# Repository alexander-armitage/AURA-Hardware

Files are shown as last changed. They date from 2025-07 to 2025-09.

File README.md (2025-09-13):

<div align="center">

# AURA
### Autonomous Universal Robotics Architecture

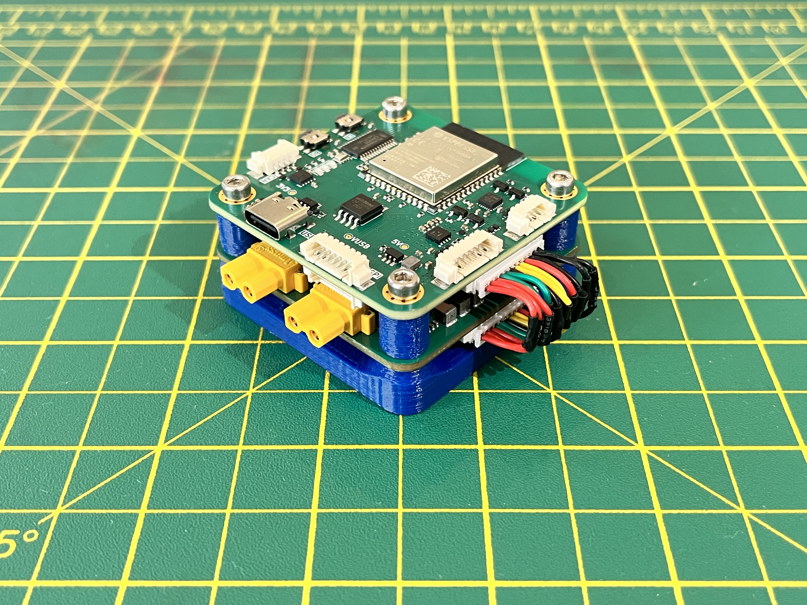
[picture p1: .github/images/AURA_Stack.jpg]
AURA PCBs Stacked


</div>

## Contents

1. [Overview](#overview)  
2. [Repository Structure](#repository-structure)
3. [License](#license)

## Overview

AURA (Autonomous Universal Robotics Architecture) is a modular set of PCBs designed for robotics applications. This repository includes schematics, layouts, and KiCad project files to facilitate prototyping and production.

The software framework to run on this hardware can be seen in another repository [here](https://github.com/alexander-armitage/AURA-Software).

### Features
#### MCU
- Dual Core 240MHz ESP32-S3
- Onboard IMU (ICM20948) 
- Onboard barometer (BMP280)
- Flash storage (128 MBit)
- SD card support
- 1x CAN connector
- 1x I2C connector
- 2x SPI connector
- 2x UART connectors
- 12x PWM output channels
- Power switching
- ESD protection

#### PDB
- 1x Battery pass-through
- 1x 5V 20A continuous output
- 2x high-current (10A) output channels
- 2S-6S LiPo battery input support
- Reverse polarity protection
- Power, Current, and Voltage sensing
- ESD protection

## Repository Structure

```
AURA-Hardware/
├── .github/              # Images for README
├── MCU_AURA/             # ESP32S3 based PCB project
│ ├── Gerber/             # Manufacturing files (JLCPCB)
│ ├── Libraries/          # Local project libraries
| ├── Pick_n_Place/       # Files to generate pick and place (JLCPCB)
│ └── MCU_AURA.kicad_pro  # Project file for KiCad
├── PDB_AURA/             # Power distribution board PCB project
│ ├── Gerber/             # Manufacturing files (JLCPCB)
│ ├── Libraries/          # Local project libraries
| ├── Pick_n_Place/       # Files to generate pick and place (JLCPCB)
│ └── PDB_AURA.kicad_pro  # Project file for KiCad
├── docs/                 # Schematics for the PCB projects
├── .gitignore            # Git ignore file
├── README.md             # Project overview
└── LICENSE               # License file
```

## License
See the [LICENSE](./LICENSE) file for more details.

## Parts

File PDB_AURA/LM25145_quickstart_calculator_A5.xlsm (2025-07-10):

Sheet: Design Regulator
LM(2)5145/46-Q1 DC-DC Controller Design Tool
About |  | xx (http://www.ti.com/pol) |  |  | = Input Box |  |  |  |  | TERMS OF USE
Step 1: Operating Specifications
 |  |  | Input Voltage ‒ Min, VIN(min) | 7.2 | V
 |  |  | Input Voltage ‒ Nom, VIN(nom) | 12.6 | V
 |  |  | Input Voltage ‒ Max, VIN(max) | 25.2 | V
 |  |  | Output Voltage, VOUT | 5 | V
 |  |  | Maximum Output Current, IOUT | 20 | A
 |  |  | Free-running Switching Frequency, FSW | 256 | kHz
 |  |  | SYNC Frequency (if used), FSW-SYNC | 256 | kHz
 |  |  | Frequency Set Resistor, RRT | 39.2 | kΩ
Step 2: Filter Inductor
 |  |  | Recommended Filter Inductance | 1.8 | µH
 |  |  | Inductance, LF | 1.8 | µH
 |  |  | Inductor DCR | 5 | mΩ
 |  |  | Pk-to-Pk Ripple Current at VIN(nom), DIL | 6.8 | Apk-pk
 |  |  | Inductor Ripple Current as a % of Max IOUT | 34.16418651 | %
 |  |  | Estimate Core Loss at VIN(nom) | 0.2 | W
Step 3: RDS(on) or Shunt-Based Current Limit
 |  |  | Shunt, RS | 6 | mΩ |  |  |  |  |  | \
 |  |  | Required Current Limit Setpoint | 20 | A
 |  |  | Current Limit Set Resistor, RILIM | 499 | Ω
 |  |  | Min Inductor Sat Current, IL(SAT) | 27.6 | A
 |  |  | Power Loss in RS at Full Load, Max VIN | 1.54 | W
Step 4: Output Capacitance
 |  |  | Output Voltage Ripple Specification | 200 | mVpk-pk
 |  |  | Minimum Ideal Output Capacitance | 16.68173169 | µF
 |  |  | Total Output Capacitance (Derated), COUT | 100 | µF
 |  |  | Maximum Permitted ESR | 28.86027509 | mΩ
 |  |  | Output Capacitor ESR | 1 | mΩ
 |  |  | Resulting Output Voltage Ripple | 34.05595917 | mVpk-pk
 |  |  | Output Capacitor Ripple Current | 2.0 | A (rms)
Step 5: Input Capacitance
 |  |  | Input Voltage Ripple Specification | 500 | mVpk-pk
 |  |  | Minimum Ideal Input Capacitance | 37.91454082 | µF
 |  |  | Total Input Capacitance (Derated), CIN | 150 | µF
 |  |  | Maximum Permitted ESR | 15.9553945 | mΩ
 |  |  | Input Capacitor ESR | 2 | mΩ
 |  |  | Resulting Input Voltage Ripple | 173.21464 | mVpk-pk
 |  |  | Input Capacitor Ripple Current | 9.9 | A (rms)
Step 6: Soft-start, UVLO
 |  |  | Soft-Start Time, tSS | 4 | ms
 |  |  | Soft-Start Capacitance, CSS | 47 | nF
 |  |  | Input Voltage UVLO Turn-On | 34 | V
 |  |  | Input Voltage UVLO Turn-Off | 30 | V
 |  |  | UVLO Upper Resistor, RUV1 | 402 | kΩ
 |  |  | UVLO Lower Resistor, RUV2 | 14.7 | kΩ
If the SYNC feature is not required, connect SYNCIN to GND
or VCC for DCM or CCM operation, respectively
Step 7: Compensation Design
 |  |  | LC Complex Pole Frequency | 12.0 | kHz
 |  |  | ESR Zero Frequency | 1591.549433 | kHz
 |  |  | Desired Crossover Frequency | 40 | kHz
 |  |  | Appropriate Midband Gain | 0.22 | V/V
 |  |  | Upper Feedback Resistor, RFB1 | 10.5 | kΩ
 |  |  | Lower Feedback Resistor, RFB2 | 2 | kΩ
 |  |  | Actual Output Voltage, VOUT | 5.000 | V
Pole & Zero Placement |  |  | FZ1 | 8.4 | kHz
Baseline P/Z Frequencies: |  |  | FZ2 | 10.8 | kHz
 |  |  | FP1 | 1591.549433 | kHz
 |  |  | FP2 | 128 | kHz
Compensation Components
 | Calculated / | Std Values | Selected |  | Actual P/Z Frequencies
RC1 | 2.3 | 2.32 | 1 | kΩ | 8.8 | kHz (FZ1)
CC1 | 8120.150167 | 8200 | 18000 | pF | 8.4 | kHz (FZ2)
CC2 | 568.1178809 | 560 | 1000 | pF | 4019.064224 | kHz (FP1)
RC2 | 71.47847597 | 71.5 | 22 | Ω | 167.9968846 | kHz (FP2)
CC3 | 1399.022554 | 1500 | 1800 | pF |  |  | ** Specify Inductor Core Loss ** | 0.4 | W
Efficiency / Power Loss Analyzer
Step 8: Efficiency
 |  |  | High-Side MOSFET (Q1) Specifications | CSD18563Q5D
 |  |  | On-State Resistance, RDS(on) | 6 | mΩ
 |  |  | Total Gate Charge, QG | 11.5 | nC
 |  |  | Gate-Drain Charge, QGD | 2.9 | nC
 |  |  | Gate-Source Charge, QGS | 3.3 | nC
 |  |  | Output Capacitance, COSS | 280 | pF
 |  |  | Gate Resistance, RG | 1.5 | Ω
 |  |  | Transconductance, gFS | 100 | S
 |  |  | Gate-Source Plateau Voltage, VGS(MP) | 3.2 | V
 |  |  | Body Diode Forward Voltage, VBD1 | 0.8 | V
 |  |  | Thermal Resistance, θJA | 50 | °C/W
 |  |  | Low-Side MOSFET (Q2) Specifications | CSD18563Q5D
 |  |  | On-State Resistance, RDS(on) | 6 | mΩ
 |  |  | Total Gate Charge, QG | 11.5 | nC
 |  |  | Output Charge, QOSS | 20 | nC
 |  |  | Output Capacitance, COSS | 280 | pF
 |  |  | Body Diode Forward Voltage, VBD2 | 0.9 | V
 |  |  | Body Diode Recovery Charge, QRR | 63 | nC
 |  |  | Thermal Resistance, θJA | 50 | °C/W
 |  |  | Antiparallel Schottky Diode (if applicable)
 |  |  | Schottky Diode Forward Voltage, VSD | 0 | V
 |  |  | Schottky Diode Recovery Charge, QRR2 | 0 | nC
Step 9: IC Power Loss
 |  |  | IC Power Dissipation | 0.07 | W
 |  |  | IC Junction Temperature Rise (est) | 3.5 | °C

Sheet: Schematic & BOM
 | ** Tie SYNCIN to VCC and GND for CCM and DCM operation, respectively **
VIN = 12.6 V, VOUT = 5 V, IOUT = 20 A, Fsw = 256 kHz, Current Limit = 20 A
Wide VIN, High Efficiency Synchronous Buck Regulator BOM
Count | Ref Des | Value | Description | Size | Part Number | MFR | Footprint (mm) | Area (mm2)
1 | CBOOT | 0.1µF | Capacitor, Ceramic,0.1µF, 25V, X7R, 20% |  | Std | Std | 1.6 x 0.8 | 1.3 |  |  |  | 2
1 | CC1 | 18000pF | Capacitor, Ceramic,18000pF, 16V, X7R, 10% |  | Std | Std | 1.0 x 0.5 | 0.5 |  |  |  | 1
1 | CC2 | 1000pF | Capacitor, Ceramic,1000pF, 50V, NP0, 5% |  | Std | Std | 1.0 x 0.5 | 0.5 |  |  |  | 1
1 | CC3 | 1800pF | Capacitor, Ceramic,1800pF, 50V, NP0, 5% |  | Std | Std | 1.0 x 0.5 | 0.5 |  |  |  | 1
1 | CS | 10pF | Capacitor, Ceramic, 10pF, 100V, X7R, 20% |  | Std | Std | 1.6 x 0.8 | 1.3 |  |  |  | 2
15 | CIN | 4.7µF | Capacitor, Ceramic, 4.7µF, 50V, X7R, 10% |  | Std | Std | 3.2 x 2.5 | 120.0 |  |  |  | 5
3 | COUT | 47µF | Capacitor, Ceramic, 47µF, 10V, X7R, 10% |  | Std | Std | 3.2 x 2.5 | 24.0 |  |  |  | 5
1 | CSS | 47nF | Capacitor, Ceramic,47nF, 16V, X7R, 10% |  | Std | Std | 1.6 x 0.8 | 1.3 |  |  |  | 2
1 | CVCC | 2.2µF | Capacitor, Ceramic,2.2µF, 25V, X7R, 20% |  | Std | Std | 2.0 x 1.25 | 2.5 |  |  |  | 3
1 | CVIN | 0.1µF | Capacitor, Ceramic,0.1µF, 50V, X7R, 20% |  | Std | Std | 1.6 x 0.8 | 1.3 |  |  |  | 2
1 | LF | 1.8µH | Inductor, 1.8µH, 5mΩ, >28A |  | Various | Various | 10.0 x 10.0 | 100.0 |  |  |  | 7
1 | Q1 | See description | MOSFET, N-CH, 80V/100V,6mΩ |  | CSD18563Q5D | TI | 5.0 x 6.0 | 30.0 |  |  |  | 1 | 1
1 | Q2 | See description | MOSFET, N-CH, 80V/100V,6mΩ |  | CSD18563Q5D | TI | 5.0 x 6.0 | 30.0 |  |  |  | 1 | 1
1 | RC1 | 1k | Resistor, Chip,1kΩ, 1/16W, 1% |  | Std | Std | 1.0 x 0.5 | 0.5 |  |  |  | 1
1 | RC2 | 22 | Resistor, Chip,22Ω, 1/16W, 1% |  | Std | Std | 1.0 x 0.5 | 0.5 |  |  |  | 1
1 | RILIM | 499 | Resistor, Chip,499Ω, 1/16W, 1% |  | Std | Std | 1.0 x 0.5 | 2.5 |  |  |  | 3
1 | RRT | 39.2k | Resistor, Chip,39.2kΩ, 1/16W, 1% |  | Std | Std | 1.0 x 0.5 | 0.5 |  |  |  | 1
1 | RFB1 | 10.5k | Resistor, Chip,10.5kΩ, 1/16W, 1% |  | Std | Std | 1.0 x 0.5 | 0.5 |  |  |  | 1
1 | RFB2 | 2k | Resistor, Chip,2kΩ, 1/16W, 1% |  | Std | Std | 1.0 x 0.5 | 0.5 |  |  |  | 1
1 | RPGOOD | 20k | Resistor, Chip,20kΩ, 1/16W, 1% |  | Std | Std | 1.0 x 0.5 | 0.5 |  |  |  | 1
1 | RS | 6mΩ | Resistor,6mΩ, 1/4W, 1% | 1206 | Std | Std | 3.2 x 1.6 | 0.0
1 | RUV1 | 402k | Resistor, Chip,402kΩ, 1/16W, 1% |  | Std | Std | 1.6 x 0.8 | 1.3 |  |  |  | 2
1 | RUV2 | 14.7k | Resistor, Chip,14.7kΩ, 1/16W, 1% |  | Std | Std | 1.0 x 0.5 | 0.5 |  |  |  | 1
1 | RVIN | 2.2 | Resistor, Chip,2.2Ω, 1/16W, 1% |  | Std | Std | 1.0 x 0.5 | 0.5 |  |  |  | 1
1 | U1 | LM25145 | IC, LM25145, PWM Controller, 6V-42V Input | VQFN-20 | LM25145RGYR | TI | 3.5 x 4.5 x 1.0 | 15.75
 |  |  |  |  | Total Solution Size (buffered by 25%) |  |  | 420.9 | mm2 = | 0.6525 | in2
NOTES:
** Inductor saturation current should be higher than the current limit setpoint at all operating temperatures **
** Effective output capacitance should be appropriately derated for applied voltage and temperature, particularly with ceramics **
 |  |  |  |  |  |  |  |  |  |  |  | 2

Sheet: EVMs
LM(2)5145/6/-Q1 Quickstart Calculator
 | LM5146-Q1-EVM12V
 | LM5145EVM-HD-20A PCB Layout
 |  | Top
 |  | Layer | x
 |  | Layer 2
 |  | Layer 3
 |  | Bottom

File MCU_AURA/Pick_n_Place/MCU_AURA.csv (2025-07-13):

Value | Reference | Footprint | JLCPCB Part#
100n | C1,C102,C103,C104,C201,C203,C204,C205,C206,C300,C301,C302,C303,C304,C305,C402 | Capacitor_SMD:C_0402_1005Metric | C1525
10u | C100,C105,C107,C202,C400 | Capacitor_SMD:C_0402_1005Metric | C15525
1u | C101,C108,C109,C401 | Capacitor_SMD:C_0402_1005Metric | C52923
4u7 | C106 | Capacitor_SMD:C_0805_2012Metric | C23733
22u | C200 | Capacitor_SMD:C_0402_1005Metric | C415703
TPD1E05U06DPYR | D100,D101,D102,D400,D401,D402,D403,D404,D405,D406,D407,D408,D409,D410 | TPD1E05U06DPYR:DIO_TPD1E05U06DPYR | C2937017
LED | D103,D104,D300 | LED_SMD:LED_0603_1608Metric | C2286
PCA9685PW,118 | IC1 | PCA9685PW_118:SOP65P640X110-28N | C2678753
W25Q128JVSIQ | IC2 | SOIC127P790X216-8N | C97521
USB_C_Receptacle_USB2.0_16P | J100 | USB-C:USB_C_Receptacle_GCT_USB4105-xx-A_16P_TopMnt_Horizontal | C19189138
532617004 | J400,J402 | 532610471:53261-0471 | C696092
532617007 | J405,J407 | 532610771:532610771 | C505276
2u2 | L101 | Inductor_SMD:L_1008_2520Metric | C92925
BSS138 | Q300,Q301,Q302 | Package_TO_SOT_SMD:SOT-23 | C7420339
10k | R1,R103,R200,R205,R206,R300,R301,R302,R303,R304,R306,R400,R401 | Resistor_SMD:R_0402_1005Metric | C25744
5k1 | R100,R101 | Resistor_SMD:R_0402_1005Metric | C25905
270R | R102 | Resistor_SMD:R_0402_1005Metric | C163474
1k | R104 | Resistor_SMD:R_0402_1005Metric | C11702
6k8 | R106 | Resistor_SMD:R_0402_1005Metric | C25917
1k5 | R107 | Resistor_SMD:R_0402_1005Metric | C25867
470R | R108,R305 | Resistor_SMD:R_0402_1005Metric | C25117
22R | R201,R202 | Resistor_SMD:R_0402_1005Metric | C25092
EVQPUC02K | S200,S201 | EVQ-PUC02k:EVQPUC02K | EVQPUC02K
TPS2115ADRBR | U100 | TPS2115ADRBR:SON65P300X300X100-9N-D | C140321
TLV62566DBVR | U101 | TLV62566DBVR:SOT95P280X145-5N | C2070898
AP2127N-1.8 | U102 | Package_TO_SOT_SMD:SOT-23 | C780749
ESP32-S3-WROOM-1 | U200 | RF_Module:ESP32-S3-WROOM-1 | C2913198
USBLC6-2SC6 | U201 | Package_TO_SOT_SMD:SOT-23-6 | C7519
TCAN1042VDRBRQ1 | U202 | TCAN1042VDRBRQ1:DRB0008F | C2652857
ICM-20948 | U300 | Sensor_Motion:InvenSense_QFN-24_3x3mm_P0.4mm | C726001
BMP280 | U301 | Package_LGA:Bosch_LGA-8_2x2.5mm_P0.65mm_ClockwisePinNumbering | C83291

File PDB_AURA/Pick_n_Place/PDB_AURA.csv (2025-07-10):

Value | Reference | Footprint | JLCPCB Part#
47n | C101,C211 | Capacitor_SMD:C_0402_1005Metric | C272875
47u | C102,C200,C201,C204,C205,C216 | Capacitor_SMD:C_1210_3225Metric | C7432791
22n | C104 | Capacitor_SMD:C_0402_1005Metric | C1532
100n | C202,C207,C208,C215,C217,C300 | Capacitor_SMD:C_0402_1005Metric | C307331
1u | C203,C218 | Capacitor_SMD:C_0402_1005Metric | C52923
2u2 | C209 | Capacitor_SMD:C_0402_1005Metric | C107369
10p | C210 | Capacitor_SMD:C_0402_1005Metric | C32949
1n | C212 | Capacitor_SMD:C_0402_1005Metric | C1523
18n | C213 | Capacitor_SMD:C_0402_1005Metric | C5448818
1n8 | C214 | Capacitor_SMD:C_0402_1005Metric | C527007
LED | D100,D200 | LED_SMD:LED_0603_1608Metric | C2286
SBR3M30P17 | D300,D301 | SBR3M30P17:SBR3M30P17 | C460953
1u8 | L200 | 125CDMCCDS-1R8MC:Untitled | C2453926
CSD18540Q5B | Q100,Q200,Q201 | CSD18540Q5B:CSD18540Q5B | C86513
HSK10N06 | Q300,Q301 | HSK10N06:HSK10N06 | C5128195
0m5 | R100 | Resistor_SMD:R_2512_6332Metric | C500733
2k2 | R101 | Resistor_SMD:R_0402_1005Metric | C25879
0R | R200 | Resistor_SMD:R_0402_1005Metric | C17168
39k | R201,R208 | Resistor_SMD:R_0402_1005Metric | C25783
10k | R202,R203,R209,R300,R302,R304,R306 | Resistor_SMD:R_0402_1005Metric | C25744
22R | R204 | Resistor_SMD:R_0402_1005Metric | C25092
2k | R205 | Resistor_SMD:R_0402_1005Metric | C4109
1k | R207,R211 | Resistor_SMD:R_0402_1005Metric | C11702
10.5k | R206 | Resistor_SMD:R_0402_1005Metric | C25850
470R | R210 | Resistor_SMD:R_0402_1005Metric | C25117
220R | R301,R305 | Resistor_SMD:R_0402_1005Metric | C25091
100R | R303,R307 | Resistor_SMD:R_0402_1005Metric | C25076
LM74700 | U100 | Package_TO_SOT_SMD:SOT-23-6 | C2941042
LM25145RGYR | U200 | LM24145RGYR:RGY0020B | C2876740
LTV-217-B-G | U300,U301 | LTV-217-B-G:SOIC127P700X210-4N | C115450
INA219AIDCNR | U302 | INA219AIDCNR:SOT65P280X145-8N | C87469

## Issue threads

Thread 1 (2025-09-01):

USB ESD Protection IC (USBLC6-2SC6) Backfeeds VUSB via D+ / D−

alexander-armitage, 2025-09-01:
When powering the MCU board through the PDB, the 5 V rail oscillates on and off, causing the onboard LED to blink. The PDB itself provides a stable 5 V output, and the MCU operates normally when powered directly via USB.

The USBLC6-2SC6 protection device appears to be backfeeding VUSB through the D+ and D− lines.

Closed 2025-09-07.

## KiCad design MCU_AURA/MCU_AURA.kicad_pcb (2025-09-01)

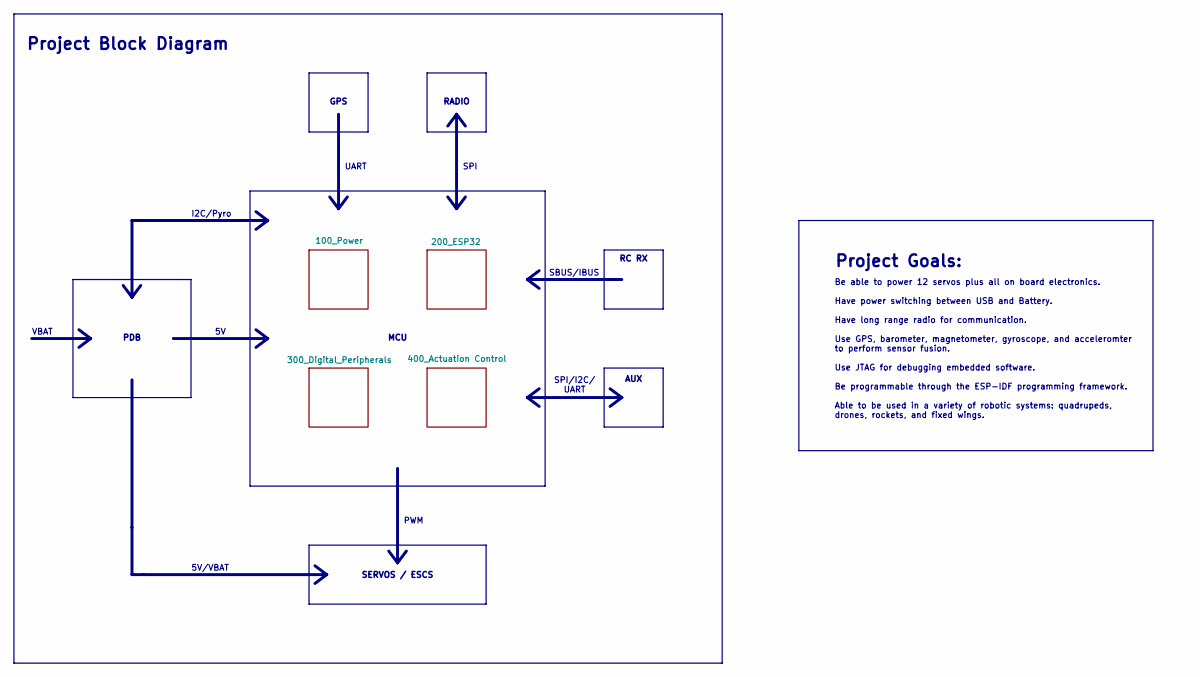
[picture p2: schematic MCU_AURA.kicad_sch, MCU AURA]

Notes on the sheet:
GPS
SPI
SPI/I2C/ UART
UART
Be able to power 12 servos plus all on board electronics. Have power switching between USB and Battery. Have long range radio for communication. Use GPS, barometer, magnetometer, gyroscope, and acceleromter to perform sensor fusion. Use JTAG for debugging embedded software. Be programmable through 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
SBUS/IBUS
RADIO
PDB
I2C/Pyro
Project Block Diagram
MCU
Project Goals:
5V/VBAT
PWM
VBAT
AUX
RC RX
SERVOS / ESCS

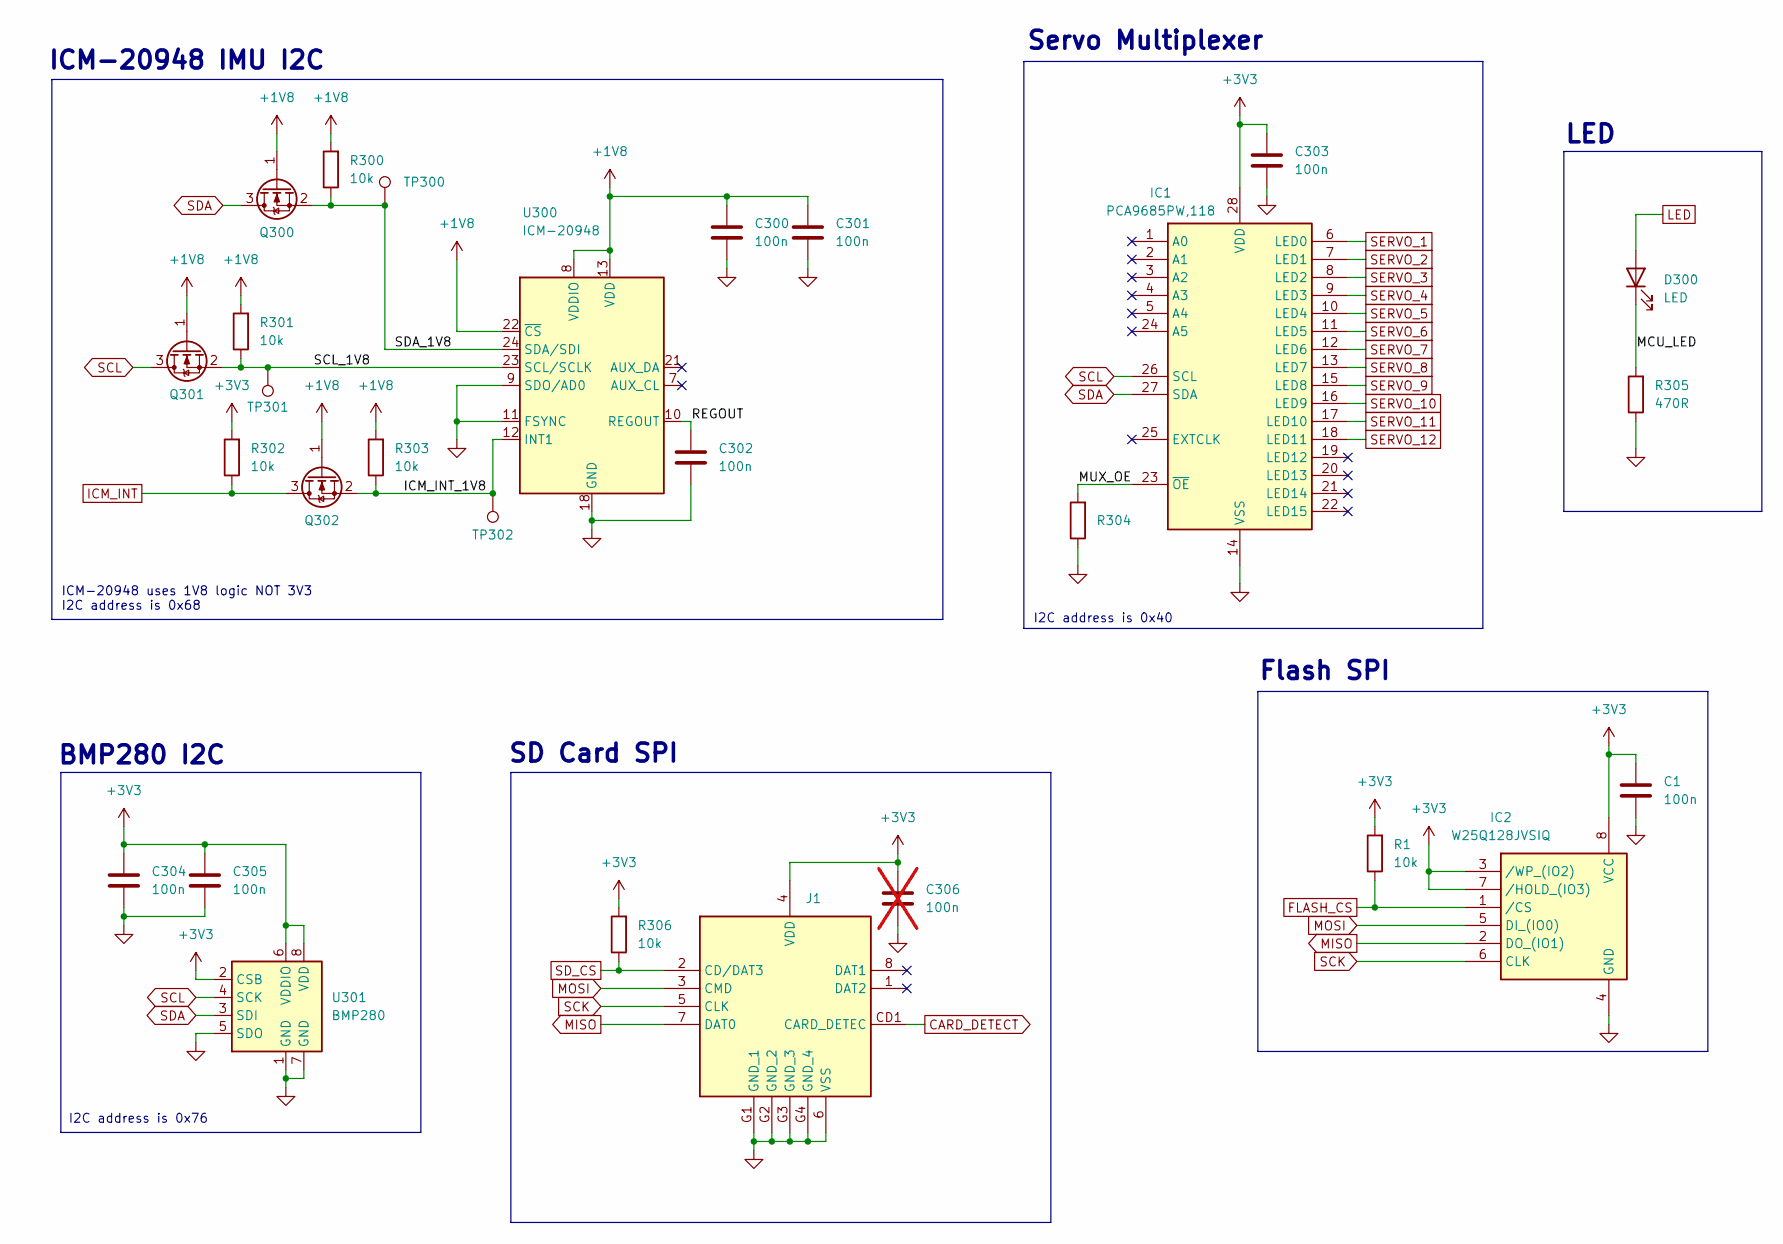
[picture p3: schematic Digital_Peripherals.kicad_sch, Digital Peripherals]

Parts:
C1, C300, C301, C302, C303, C304, C305: 100n; C_0402_1005Metric
C306: 100n; C_0402_1005Metric; not fitted
D300: LED; LED_0603_1608Metric
IC1: PCA9685PW,118; SOP65P640X110-28N; Manufacturer_Part_Number PCA9685PW,118; Mouser Part Number 771-PCA9685PW,118
IC2: W25Q128JVSIQ; SOIC127P790X216-8N; Manufacturer_Part_Number W25Q128JVSIQ; Mouser Part Number 454-W25Q128JVSIQ
J1: TF-CARD_H1.8; TFCARDH18; Manufacturer_Part_Number TF-CARD H1.8
Q300, Q301, Q302: BSS138; SOT-23
R1, R300, R301, R302, R303, R304, R306: 10k; R_0402_1005Metric
R305: 470R; R_0402_1005Metric
TP300, TP301, TP302: TestPoint; TestPoint_Pad_D1.0mm
U300: ICM-20948; InvenSense_QFN-24_3x3mm_P0.4mm
U301: BMP280; Bosch_LGA-8_2x2.5mm_P0.65mm_ClockwisePinNumbering

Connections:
+1V8: C300.1, C301.1, Q300.1 (G), Q301.1 (G), Q302.1 (G), R300.2, R301.2, R303.2, U300.8 (VDDIO), U300.13 (VDD), U300.22 (~CS); also elsewhere on the board
+3V3: C1.1, C303.1, C304.1, C305.1, C306.1, IC1.28 (VDD), IC2.3 (/WP_(IO2)), IC2.7 (/HOLD_(IO3)), IC2.8 (VCC), J1.4 (VDD), R1.2, R302.2, R306.2, U301.2 (CSB), U301.6 (VDDIO), U301.8 (VDD); also elsewhere on the board
/300_Digital_Peripherals/ICM_INT_1V8: Q302.2 (S), R303.1, TP302.1, U300.12 (INT1)
/300_Digital_Peripherals/MCU_LED: D300.1 (K), R305.2
/300_Digital_Peripherals/MUX_OE: IC1.23 (~OE), R304.2
/300_Digital_Peripherals/REGOUT: C302.1, U300.10 (REGOUT)
/300_Digital_Peripherals/SCL_1V8: Q301.2 (S), R301.1, TP301.1, U300.23 (SCL/SCLK)
/300_Digital_Peripherals/SDA_1V8: Q300.2 (S), R300.1, TP300.1, U300.24 (SDA/SDI)
CARD_DETECT: J1.CD1 (CARD_DETEC); also elsewhere on the board
FLASH_CS: IC2.1 (/CS), R1.1; also elsewhere on the board
GND: C1.2, C300.2, C301.2, C302.2, C303.2, C304.2, C305.2, C306.2, IC1.14 (VSS), IC2.4 (GND), J1.6 (VSS), J1.G1 (GND_1), J1.G2 (GND_2), J1.G3 (GND_3), J1.G4 (GND_4), R304.1, R305.1, U300.9 (SDO/AD0), U300.11 (FSYNC), U300.18 (GND), U300.20 (GND), U301.1 (GND), U301.5 (SDO), U301.7 (GND); also elsewhere on the board
ICM_INT: Q302.3 (D), R302.1; also elsewhere on the board
LED: D300.2 (A); also elsewhere on the board
MISO: IC2.2 (DO_(IO1)), J1.7 (DAT0); also elsewhere on the board
MOSI: IC2.5 (DI_(IO0)), J1.3 (CMD); also elsewhere on the board
SCK: IC2.6 (CLK), J1.5 (CLK); also elsewhere on the board
SCL: IC1.26 (SCL), Q301.3 (D), U301.4 (SCK); also elsewhere on the board
SDA: IC1.27 (SDA), Q300.3 (D), U301.3 (SDI); also elsewhere on the board
SD_CS: J1.2 (CD/DAT3), R306.1; also elsewhere on the board
SERVO_1: IC1.6 (LED0); also elsewhere on the board
SERVO_2: IC1.7 (LED1); also elsewhere on the board
SERVO_3: IC1.8 (LED2); also elsewhere on the board
SERVO_4: IC1.9 (LED3); also elsewhere on the board
SERVO_5: IC1.10 (LED4); also elsewhere on the board
SERVO_6: IC1.11 (LED5); also elsewhere on the board
SERVO_7: IC1.12 (LED6); also elsewhere on the board
SERVO_8: IC1.13 (LED7); also elsewhere on the board
SERVO_9: IC1.15 (LED8); also elsewhere on the board
SERVO_10: IC1.16 (LED9); also elsewhere on the board
SERVO_11: IC1.17 (LED10); also elsewhere on the board
SERVO_12: IC1.18 (LED11); also elsewhere on the board

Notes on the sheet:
Flash SPI
I2C address is 0x40
I2C address is 0x76
BMP280 I2C
SD Card SPI
ICM-20948 IMU I2C
Servo Multiplexer
ICM-20948 uses 1V8 logic NOT 3V3 I2C address is 0x68
LED

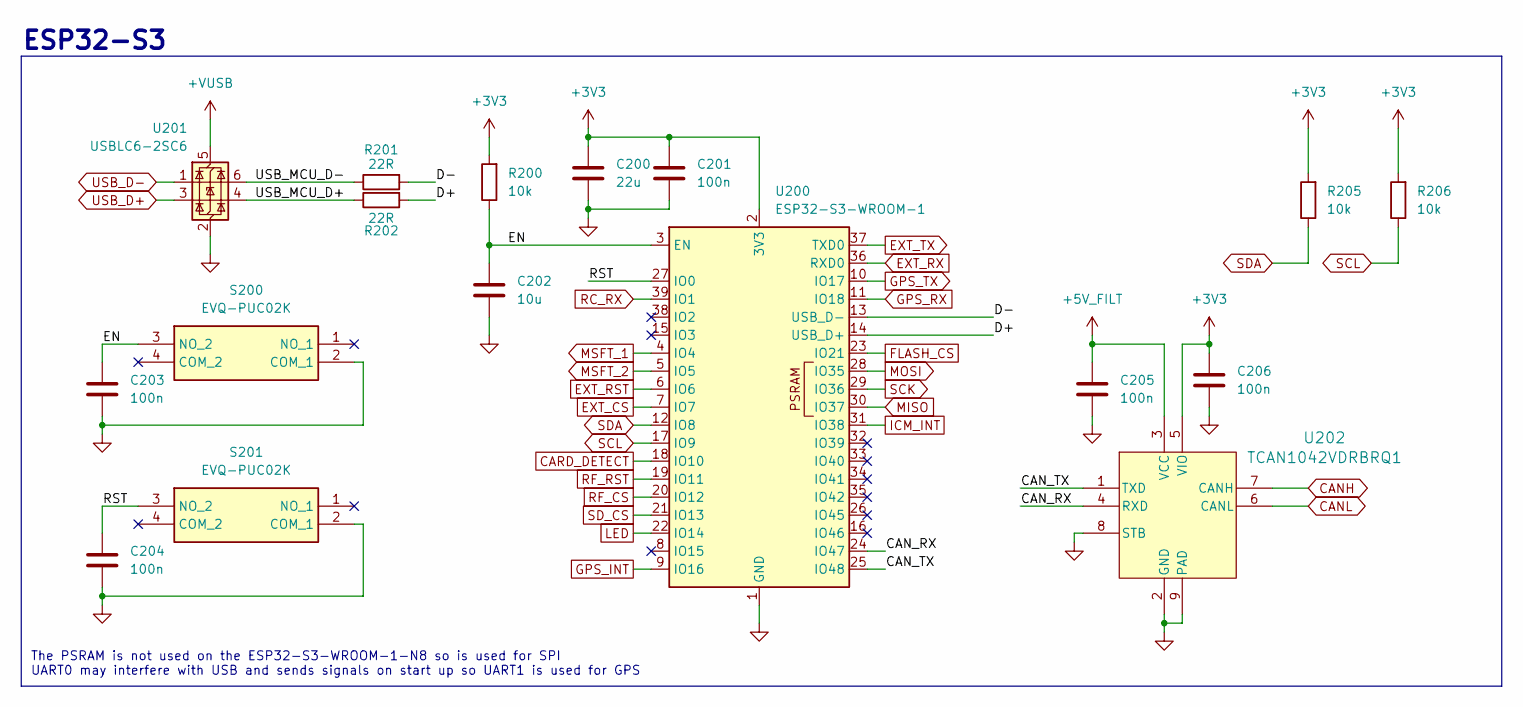
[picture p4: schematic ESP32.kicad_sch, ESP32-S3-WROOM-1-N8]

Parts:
C200: 22u; C_0402_1005Metric
C201, C203, C204, C205, C206: 100n; C_0402_1005Metric
C202: 10u; C_0402_1005Metric
R200, R205, R206: 10k; R_0402_1005Metric
R201, R202: 22R; R_0402_1005Metric
S200, S201: EVQ-PUC02K; EVQPUC02K; Manufacturer_Part_Number EVQ-PUC02K; Mouser Part Number 667-EVQ-PUC02K
U200: ESP32-S3-WROOM-1
U201: USBLC6-2SC6; SOT-23-6
U202: TCAN1042VDRBRQ1; DRB0008F

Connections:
+3V3: C200.1, C201.1, C206.1, R200.2, R205.2, R206.2, U200.2 (3V3), U202.5 (VIO); also elsewhere on the board
+5V_FILT: C205.1, U202.3 (VCC); also elsewhere on the board
+VUSB: U201.5 (VBUS); also elsewhere on the board
/200_ESP32/CAN_RX: U200.24 (IO47), U202.4 (RXD)
/200_ESP32/CAN_TX: U200.25 (IO48), U202.1 (TXD)
/200_ESP32/D+: R202.2, U200.14 (USB_D+)
/200_ESP32/D-: R201.2, U200.13 (USB_D-)
/200_ESP32/EN: C202.1, C203.1, R200.1, S200.3 (NO_2), U200.3 (EN)
/200_ESP32/RST: C204.1, S201.3 (NO_2), U200.27 (IO0)
/200_ESP32/USB_MCU_D+: R202.1, U201.4 (I/O2)
/200_ESP32/USB_MCU_D-: R201.1, U201.6 (I/O1)
CANH: U202.7 (CANH); also elsewhere on the board
CANL: U202.6 (CANL); also elsewhere on the board
CARD_DETECT: U200.18 (IO10); also elsewhere on the board
EXT_CS: U200.7 (IO7); also elsewhere on the board
EXT_RST: U200.6 (IO6); also elsewhere on the board
EXT_RX: U200.36 (RXD0); also elsewhere on the board
EXT_TX: U200.37 (TXD0); also elsewhere on the board
FLASH_CS: U200.23 (IO21); also elsewhere on the board
GND: C200.2, C201.2, C202.2, C203.2, C204.2, C205.2, C206.2, S200.2 (COM_1), S201.2 (COM_1), U200.1 (GND), U200.40 (GND), U200.41 (GND), U201.2 (GND), U202.2 (GND), U202.8 (STB), U202.9 (PAD); also elsewhere on the board
GPS_INT: U200.9 (IO16); also elsewhere on the board
GPS_RX: U200.11 (IO18); also elsewhere on the board
GPS_TX: U200.10 (IO17); also elsewhere on the board
ICM_INT: U200.31 (IO38); also elsewhere on the board
LED: U200.22 (IO14); also elsewhere on the board
MISO: U200.30 (IO37); also elsewhere on the board
MOSI: U200.28 (IO35); also elsewhere on the board
MSFT_1: U200.4 (IO4); also elsewhere on the board
MSFT_2: U200.5 (IO5); also elsewhere on the board
RC_RX: U200.39 (IO1); also elsewhere on the board
RF_CS: U200.20 (IO12); also elsewhere on the board
RF_RST: U200.19 (IO11); also elsewhere on the board
SCK: U200.29 (IO36); also elsewhere on the board
SCL: R206.1, U200.17 (IO9); also elsewhere on the board
SDA: R205.1, U200.12 (IO8); also elsewhere on the board
SD_CS: U200.21 (IO13); also elsewhere on the board
USB_D+: U201.3 (I/O2); also elsewhere on the board
USB_D-: U201.1 (I/O1); also elsewhere on the board

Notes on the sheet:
The PSRAM is not used on the ESP32-S3-WROOM-1-N8 so is used for SPI UART0 may interfere with USB and sends signals on start up so UART1 is used for GPS
ESP32-S3

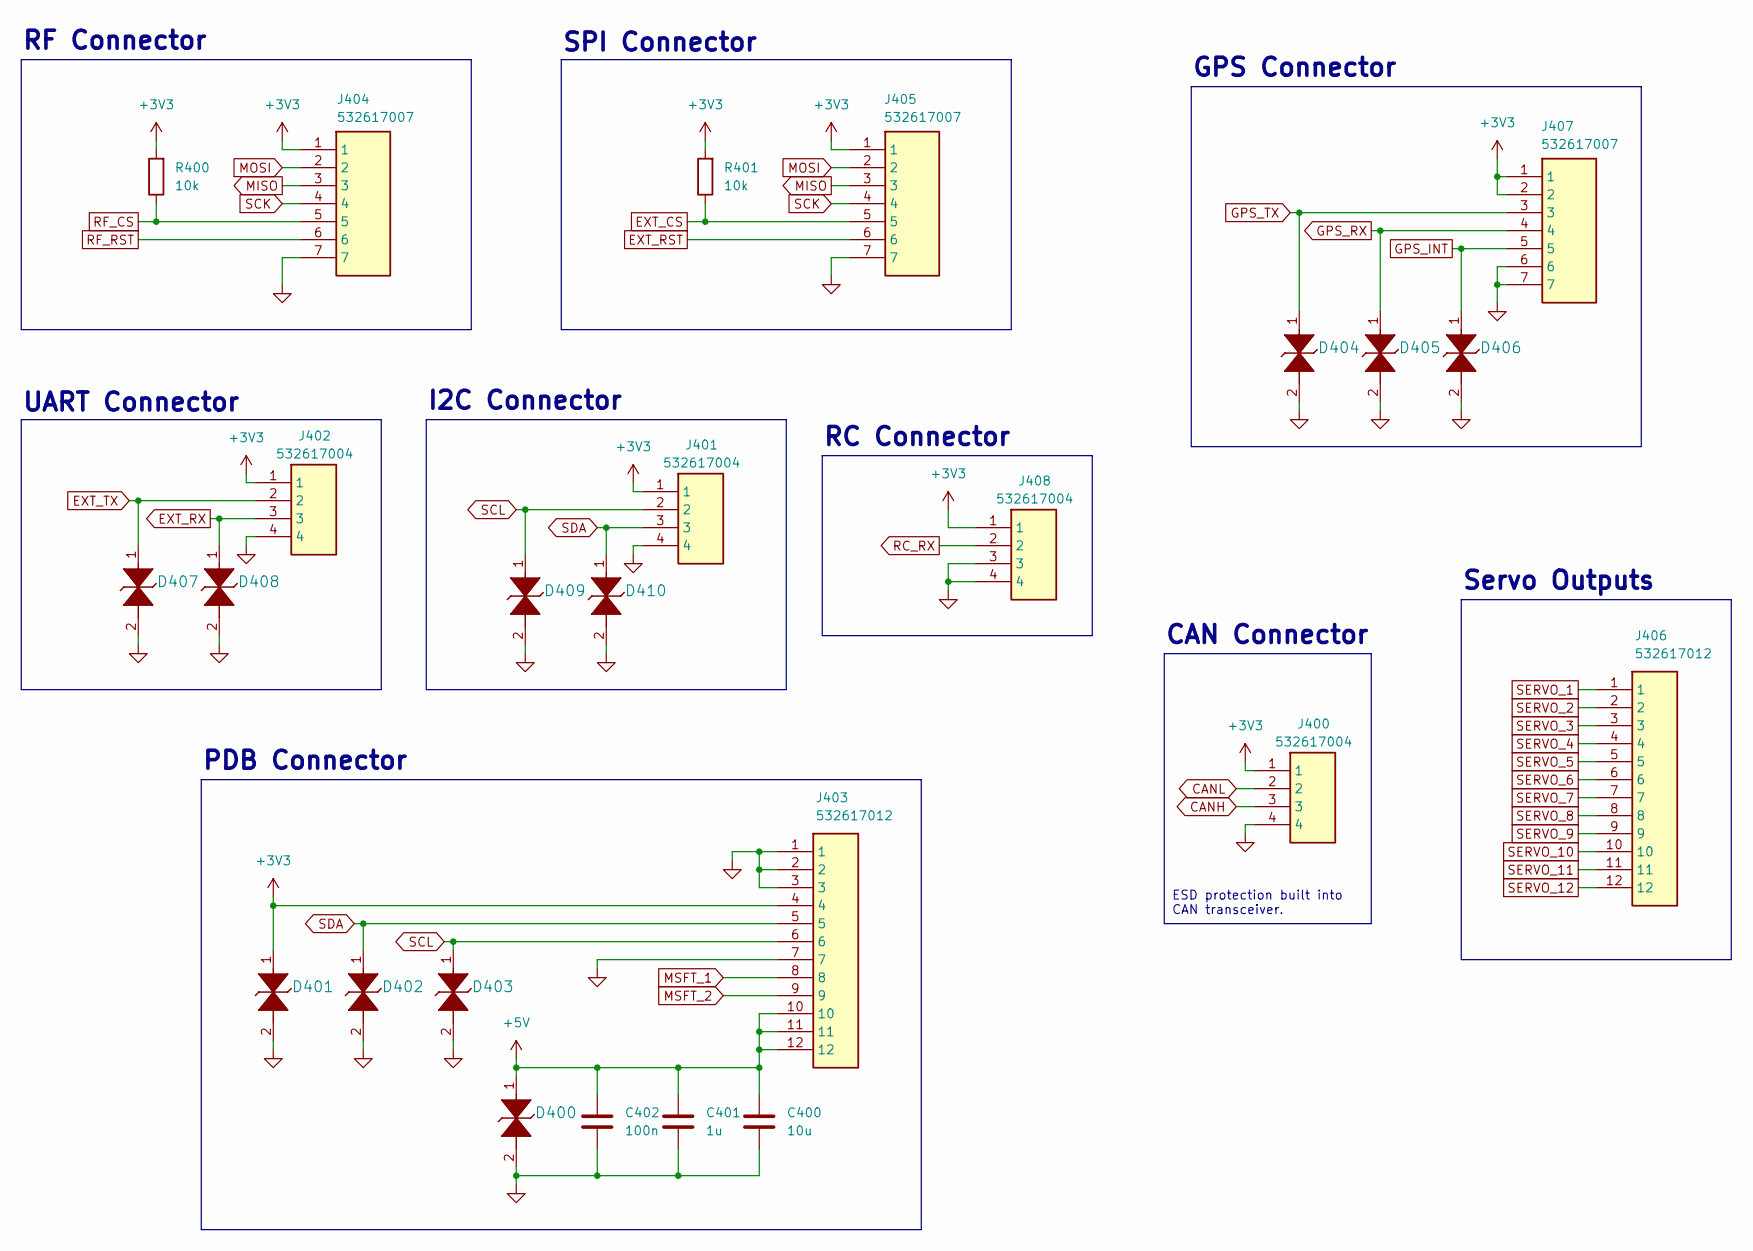
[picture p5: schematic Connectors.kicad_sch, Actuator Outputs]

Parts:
C400: 10u; C_0402_1005Metric
C401: 1u; C_0402_1005Metric
C402: 100n; C_0402_1005Metric
D400, D401, D402, D403, D404, D405, D406, D407, D408, D409, D410: TPD1E05U06DPYR; DIO_TPD1E05U06DPYR
J400, J401, J402, J408: 532617004; 53261-0471; Manufacturer_Part_Number 532617004
J403, J406: 532617012; 53261-1271; Manufacturer_Part_Number 532617012
J404, J405, J407: 532617007; 532610771; Manufacturer_Part_Number 532617007
R400, R401: 10k; R_0402_1005Metric

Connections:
+3V3: D401.1, J400.1, J401.1, J402.1, J403.4, J404.1, J405.1, J407.1, J407.2, J408.1, R400.2, R401.2; also elsewhere on the board
+5V: C400.1, C401.1, C402.1, D400.1, J403.10, J403.11, J403.12; also elsewhere on the board
CANH: J400.3; also elsewhere on the board
CANL: J400.2; also elsewhere on the board
EXT_CS: J405.5, R401.1; also elsewhere on the board
EXT_RST: J405.6; also elsewhere on the board
EXT_RX: D408.1, J402.3; also elsewhere on the board
EXT_TX: D407.1, J402.2; also elsewhere on the board
GND: C400.2, C401.2, C402.2, D400.2, D401.2, D402.2, D403.2, D404.2, D405.2, D406.2, D407.2, D408.2, D409.2, D410.2, J400.4, J401.4, J402.4, J403.1, J403.2, J403.3, J403.7, J404.7, J405.7, J407.6, J407.7, J408.3, J408.4; also elsewhere on the board
GPS_INT: D406.1, J407.5; also elsewhere on the board
GPS_RX: D405.1, J407.4; also elsewhere on the board
GPS_TX: D404.1, J407.3; also elsewhere on the board
MISO: J404.3, J405.3; also elsewhere on the board
MOSI: J404.2, J405.2; also elsewhere on the board
MSFT_1: J403.8; also elsewhere on the board
MSFT_2: J403.9; also elsewhere on the board
RC_RX: J408.2; also elsewhere on the board
RF_CS: J404.5, R400.1; also elsewhere on the board
RF_RST: J404.6; also elsewhere on the board
SCK: J404.4, J405.4; also elsewhere on the board
SCL: D403.1, D409.1, J401.2, J403.6; also elsewhere on the board
SDA: D402.1, D410.1, J401.3, J403.5; also elsewhere on the board
SERVO_1: J406.1; also elsewhere on the board
SERVO_2: J406.2; also elsewhere on the board
SERVO_3: J406.3; also elsewhere on the board
SERVO_4: J406.4; also elsewhere on the board
SERVO_5: J406.5; also elsewhere on the board
SERVO_6: J406.6; also elsewhere on the board
SERVO_7: J406.7; also elsewhere on the board
SERVO_8: J406.8; also elsewhere on the board
SERVO_9: J406.9; also elsewhere on the board
SERVO_10: J406.10; also elsewhere on the board
SERVO_11: J406.11; also elsewhere on the board
SERVO_12: J406.12; also elsewhere on the board

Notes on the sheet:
I2C Connector
GPS Connector
RC Connector
SPI Connector
ESD protection built into CAN transceiver.
RF Connector
Servo Outputs
PDB Connector
UART Connector
CAN Connector

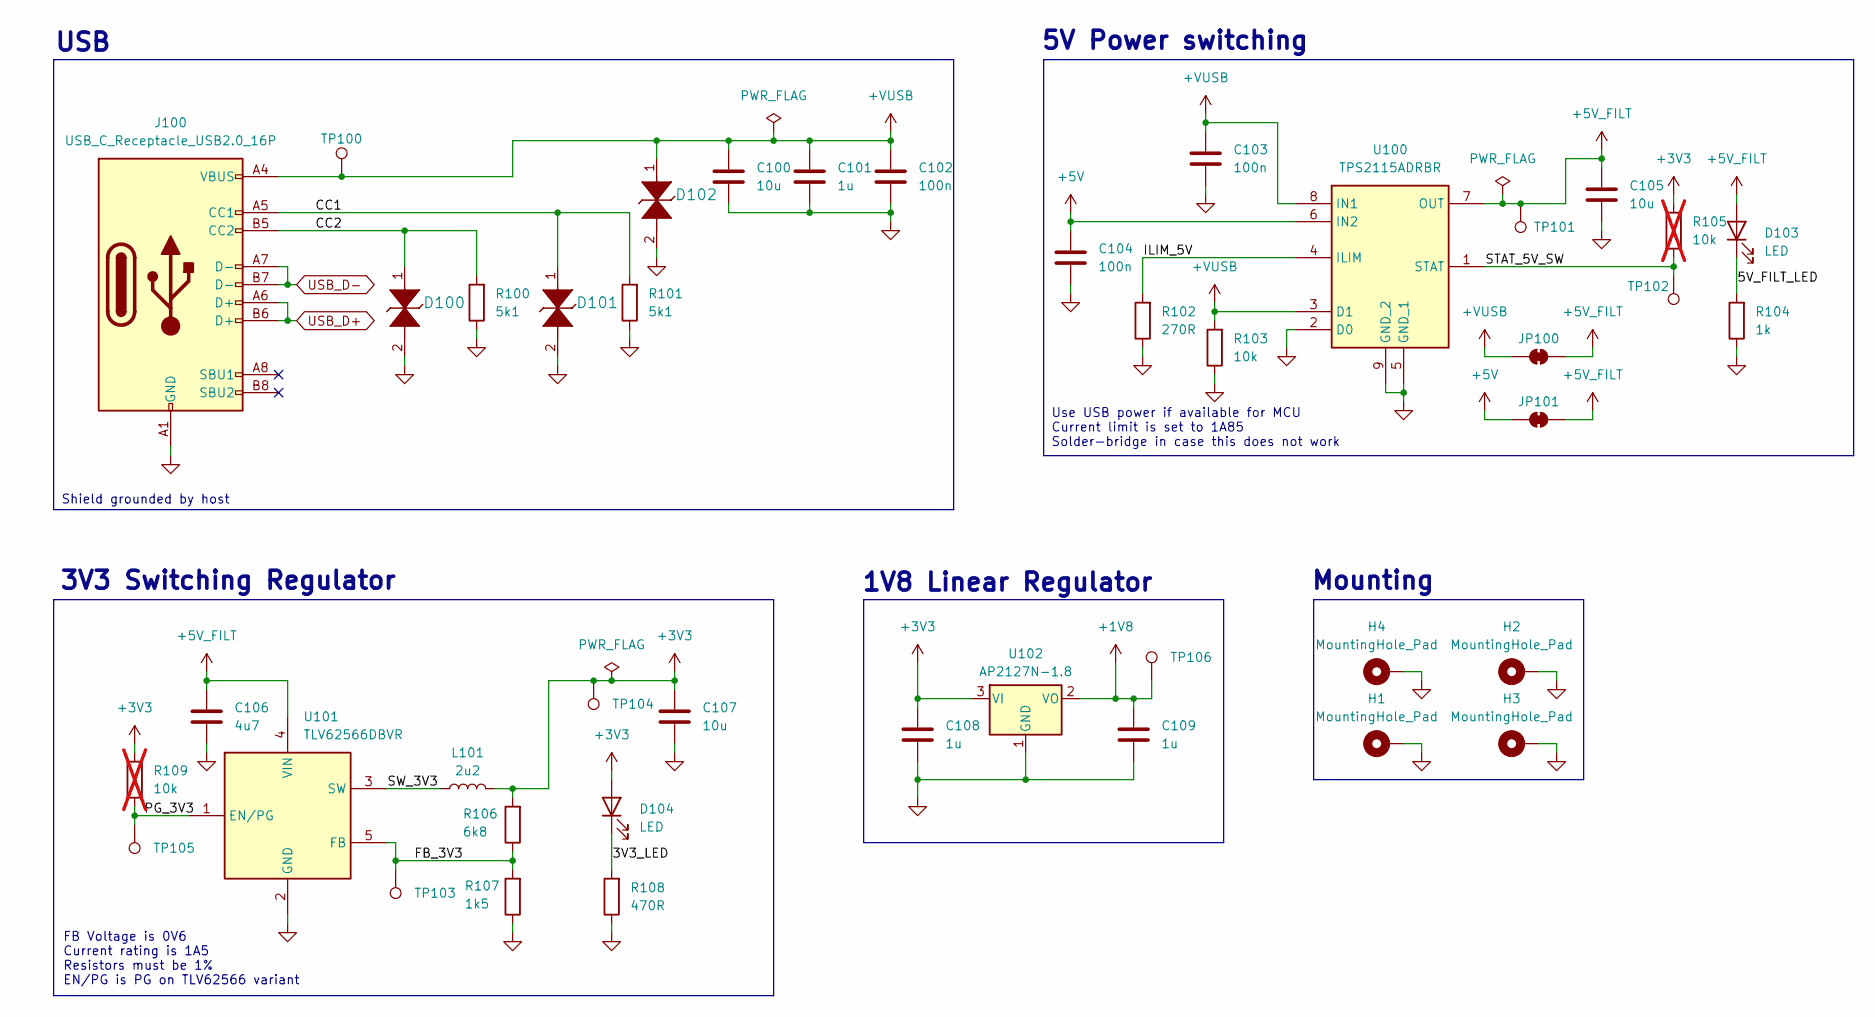
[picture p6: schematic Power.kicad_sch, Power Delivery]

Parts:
C100, C105, C107: 10u; C_0402_1005Metric
C101, C108, C109: 1u; C_0402_1005Metric
C102, C103, C104: 100n; C_0402_1005Metric
C106: 4u7; C_0402_1005Metric
D100, D101, D102: TPD1E05U06DPYR; DIO_TPD1E05U06DPYR
D103, D104: LED; LED_0603_1608Metric
H1, H2, H3, H4: MountingHole_Pad; MountingHole_3.2mm_M3_Pad_Via
J100: USB_C_Receptacle_USB2.0_16P; USB_C_Receptacle_GCT_USB4105-xx-A_16P_TopMnt_Horizontal
JP100, JP101: SolderJumper_2_Bridged; SolderJumper-2_P1.3mm_Open_RoundedPad1.0x1.5mm
L101: 2u2; L_1008_2520Metric
R100, R101: 5k1; R_0402_1005Metric
R102: 270R; R_0402_1005Metric
R103: 10k; R_0402_1005Metric
R104: 1k; R_0402_1005Metric
R105, R109: 10k; R_0402_1005Metric; not fitted
R106: 6k8; R_0402_1005Metric
R107: 1k5; R_0402_1005Metric
R108: 470R; R_0402_1005Metric
TP100, TP101, TP102, TP103, TP104, TP105, TP106: TestPoint; TestPoint_Pad_D1.0mm
U100: TPS2115ADRBR; SON65P300X300X100-9N-D; Manufacturer_Part_Number TPS2115ADRBR; Mouser Part Number 595-TPS2115ADRBR
U101: TLV62566DBVR; SOT95P280X145-5N; Manufacturer_Part_Number TLV62566DBVR; Mouser Part Number 595-TLV62566DBVR
U102: AP2127N-1.8; SOT-23

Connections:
+1V8: C109.1, TP106.1, U102.2 (VO); also elsewhere on the board
+3V3: C107.1, C108.1, D104.2 (A), L101.2, R105.2, R106.2, R109.2, TP104.1, U102.3 (VI); also elsewhere on the board
+5V: C104.1, JP101.1 (A), U100.6 (IN2); also elsewhere on the board
+5V_FILT: C105.1, C106.1, D103.2 (A), JP100.2 (B), JP101.2 (B), TP101.1, U100.7 (OUT), U101.4 (VIN); also elsewhere on the board
+VUSB: C100.1, C101.1, C102.1, C103.1, D102.1, J100.A4 (VBUS), J100.A9 (VBUS), J100.B4 (VBUS), J100.B9 (VBUS), JP100.1 (A), R103.2, TP100.1, U100.3 (D1), U100.8 (IN1); also elsewhere on the board
/100_Power/3V3_LED: D104.1 (K), R108.2
/100_Power/5V_FILT_LED: D103.1 (K), R104.2
/100_Power/CC1: D101.1, J100.A5 (CC1), R101.2
/100_Power/CC2: D100.1, J100.B5 (CC2), R100.2
/100_Power/FB_3V3: R106.1, R107.2, TP103.1, U101.5 (FB)
/100_Power/ILIM_5V: R102.2, U100.4 (ILIM)
/100_Power/PG_3V3: R109.1, TP105.1, U101.1 (EN/PG)
/100_Power/STAT_5V_SW: R105.1, TP102.1, U100.1 (STAT)
/100_Power/SW_3V3: L101.1, U101.3 (SW)
GND: C100.2, C101.2, C102.2, C103.2, C104.2, C105.2, C106.2, C107.2, C108.2, C109.2, D100.2, D101.2, D102.2, H1.1, H2.1, H3.1, H4.1, J100.A1 (GND), J100.A12 (GND), J100.B1 (GND), J100.B12 (GND), R100.1, R101.1, R102.1, R103.1, R104.1, R107.1, R108.1, U100.2 (D0), U100.5 (GND_1), U100.9 (GND_2), U101.2 (GND), U102.1 (GND); also elsewhere on the board
USB_D+: J100.A6 (D+), J100.B6 (D+); also elsewhere on the board
USB_D-: J100.A7 (D-), J100.B7 (D-); also elsewhere on the board

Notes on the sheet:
Mounting
Use USB power if available for MCU Current limit is set to 1A85 Solder-bridge in case this does not work
1V8 Linear Regulator
USB
Shield grounded by host
3V3 Switching Regulator
5V Power switching
FB Voltage is 0V6 Current rating is 1A5 Resistors must be 1% EN/PG is PG on TLV62566 variant

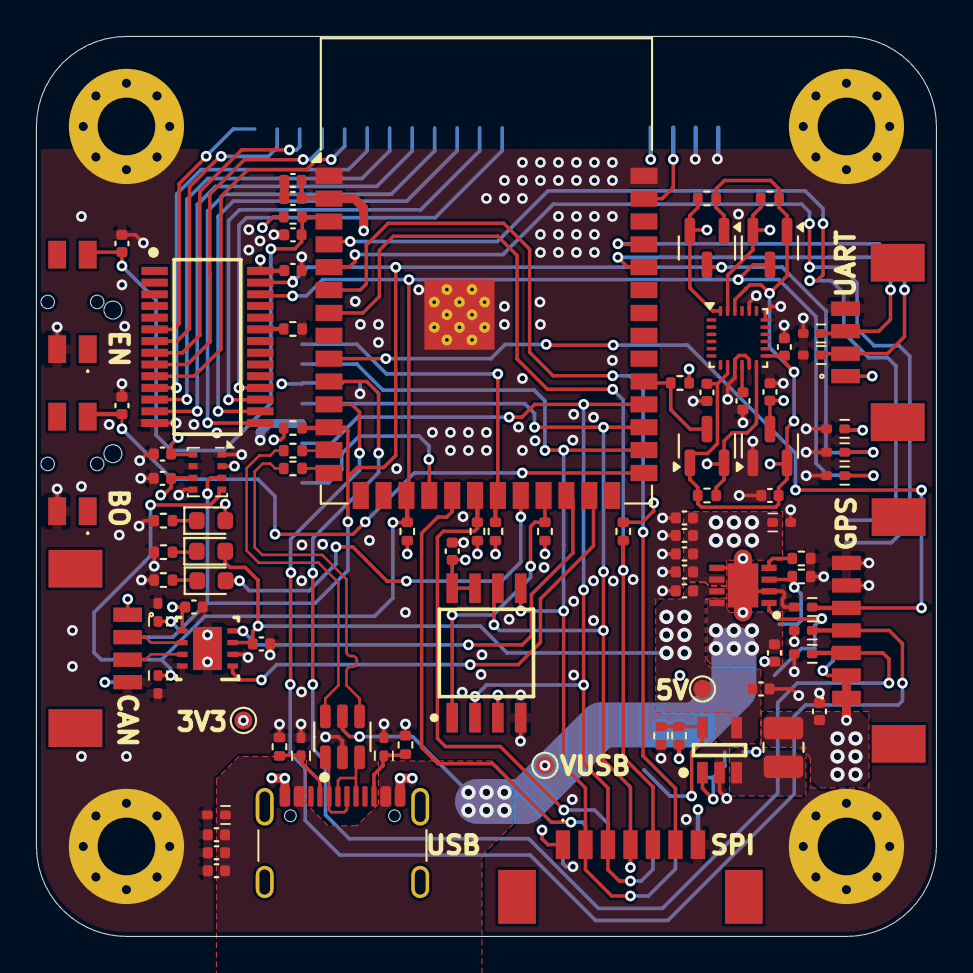
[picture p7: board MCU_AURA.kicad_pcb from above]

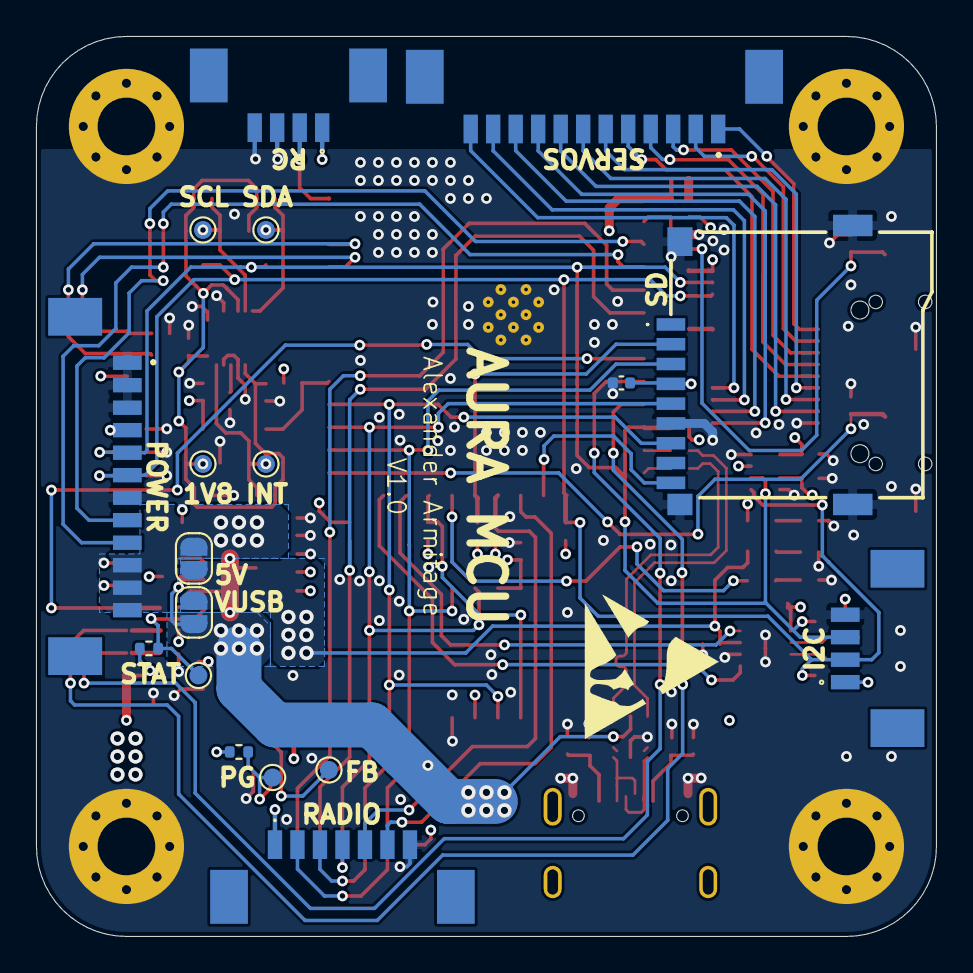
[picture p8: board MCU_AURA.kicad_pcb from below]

Board: 4 copper layers, 50.0 x 50.0 mm, 113 parts (18 on the bottom side), 67 nets.

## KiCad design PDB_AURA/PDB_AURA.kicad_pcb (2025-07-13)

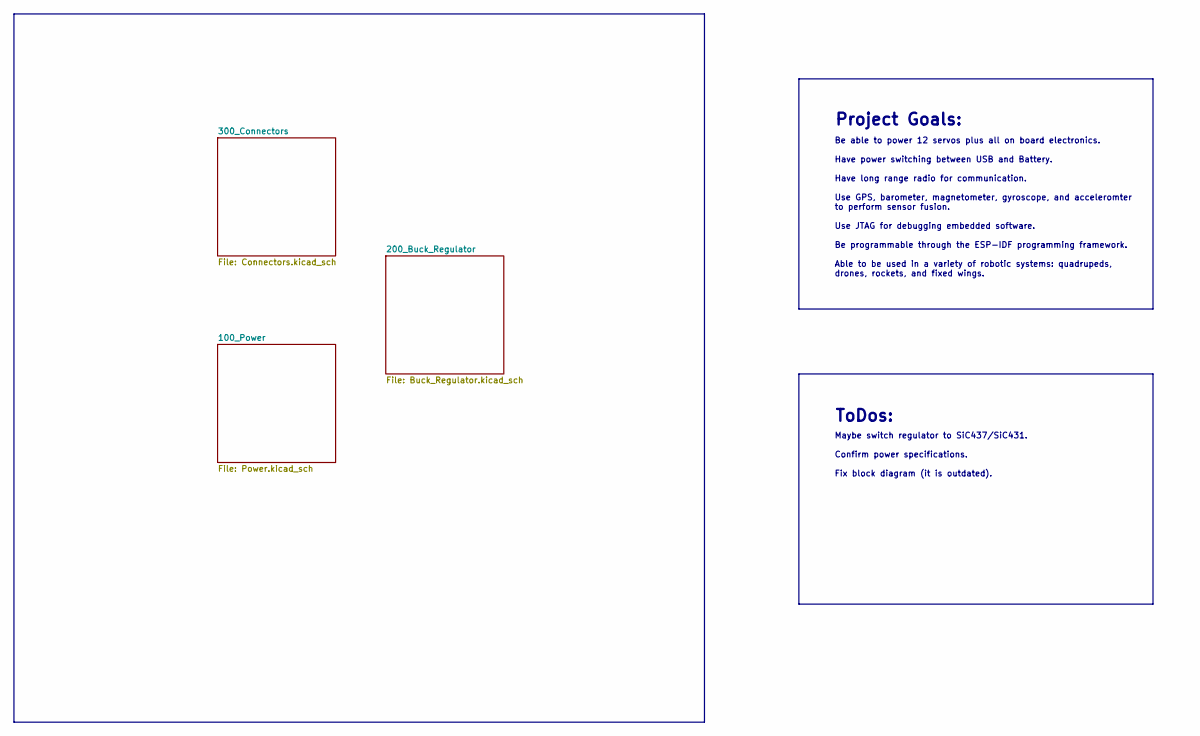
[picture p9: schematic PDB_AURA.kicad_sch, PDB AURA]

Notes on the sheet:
ToDos:
Be able to power 12 servos plus all on board electronics. Have power switching between USB and Battery. Have long range radio for communication. Use GPS, barometer, magnetometer, gyroscope, and acceleromter to perform sensor fusion. Use JTAG for debugging embedded software. Be programmable through 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
Maybe switch regulator to SiC437/SiC431. Confirm power specifications. Fix block diagram (it is outdated).
Project Goals:

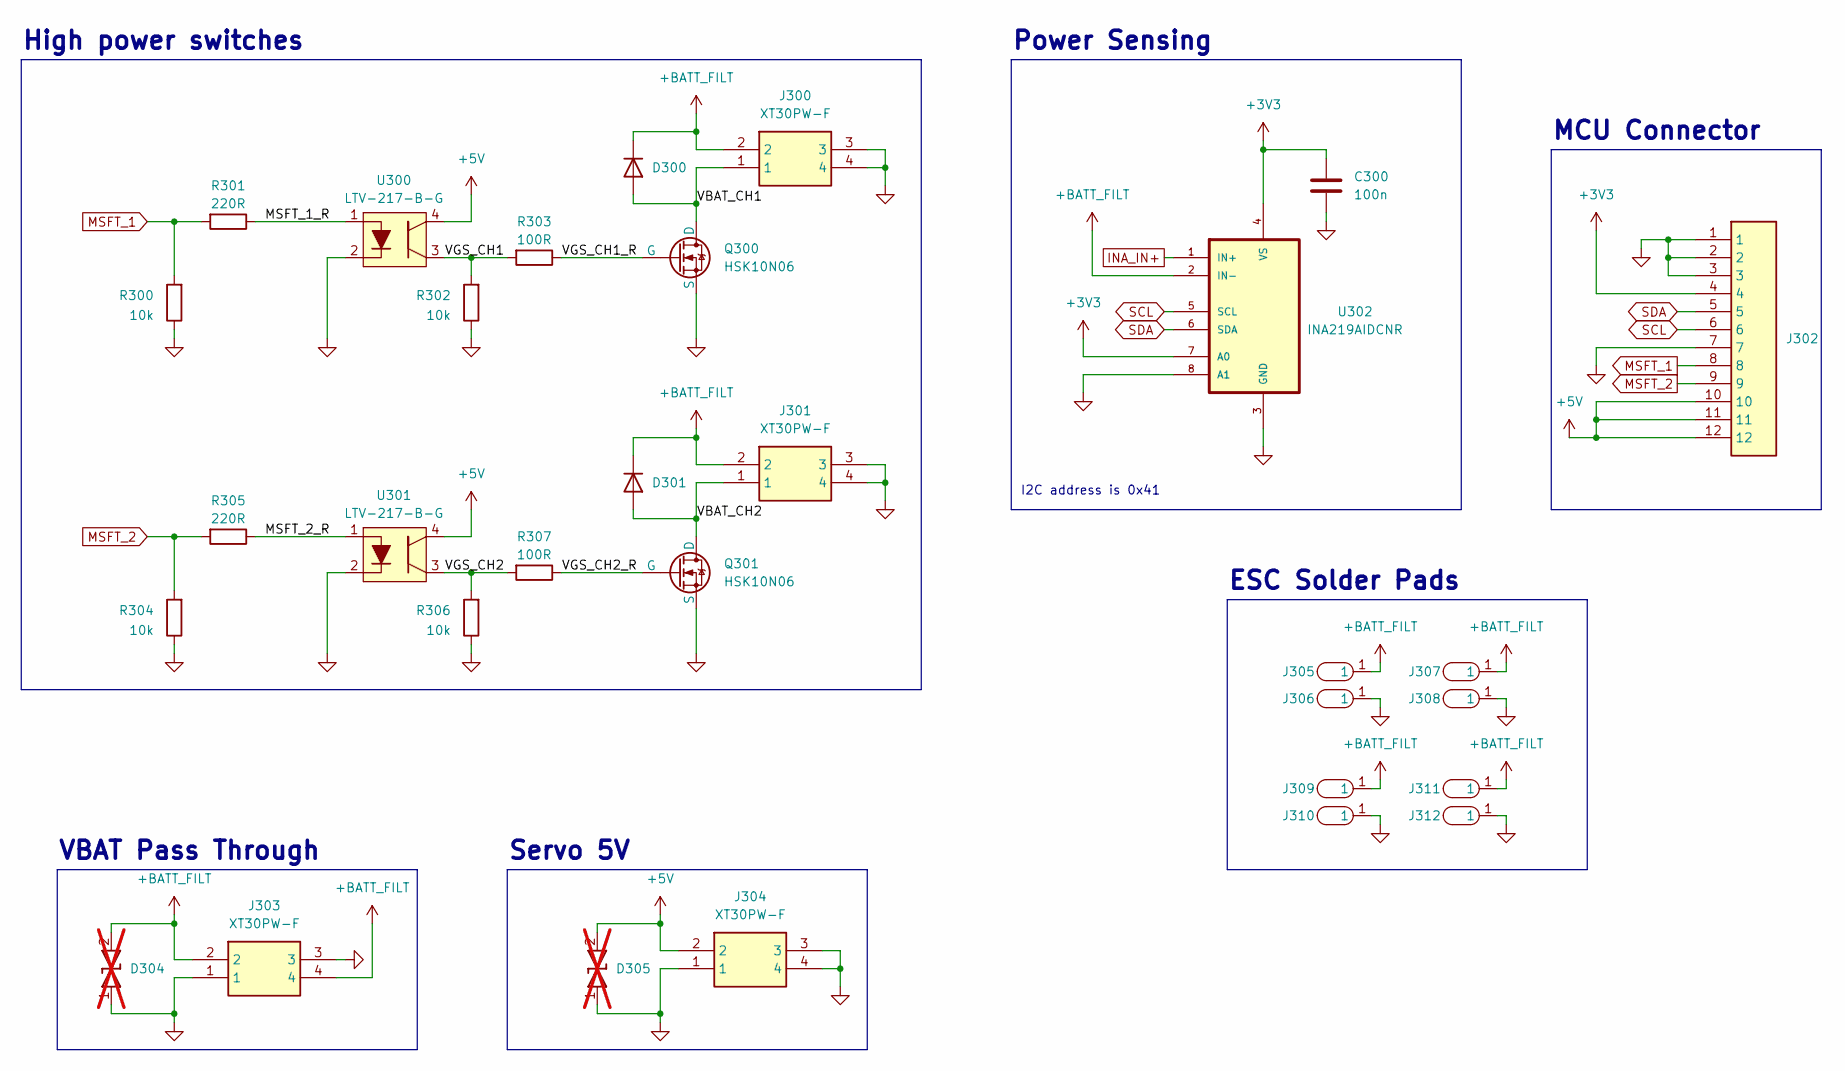
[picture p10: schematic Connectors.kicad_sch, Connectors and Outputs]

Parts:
C300: 100n; C_0402_1005Metric
D300, D301: SBR3M30P17
D304, D305: SMBJ33CA; DIONM5436X244N; Manufacturer_Part_Number SMBJ33CA; Mouser Part Number 78-SMBJ33CA; not fitted
J300, J301, J303, J304: XT30PW-F; XT30PWF; Manufacturer_Part_Number XT30PW-F
J302: 532617012; 53261-1271; Manufacturer_Part_Number 532617012
J305, J306, J307, J308, J309, J310, J311, J312: PWR_SOLDER_PAD
Q300, Q301: HSK10N06
R300, R302, R304, R306: 10k; R_0402_1005Metric
R301, R305: 220R; R_0402_1005Metric
R303, R307: 100R; R_0402_1005Metric
U300, U301: LTV-217-B-G; SOIC127P700X210-4N
U302: INA219AIDCNR; SOT65P280X145-8N

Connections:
+3V3: C300.1, J302.4, U302.4 (VS), U302.7 (A0)
+5V: D305.2, J302.10, J302.11, J302.12, J304.2, U300.4, U301.4; also elsewhere on the board
+BATT_FILT: D300.1 (K), D301.1 (K), D304.2, J300.2, J301.2, J303.2, J303.4, J305.1, J307.1, J309.1, J311.1, U302.2 (IN-); also elsewhere on the board
/300_Connectors/MSFT_1_R: R301.1, U300.1
/300_Connectors/MSFT_2_R: R305.1, U301.1
/300_Connectors/VBAT_CH1: D300.2 (A), J300.1, Q300.2 (D)
/300_Connectors/VBAT_CH2: D301.2 (A), J301.1, Q301.2 (D)
/300_Connectors/VGS_CH1: R302.2, R303.2, U300.3
/300_Connectors/VGS_CH1_R: Q300.1 (G), R303.1
/300_Connectors/VGS_CH2: R306.2, R307.2, U301.3
/300_Connectors/VGS_CH2_R: Q301.1 (G), R307.1
GND: C300.2, D304.1, D305.1, J300.3, J300.4, J301.3, J301.4, J302.1, J302.2, J302.3, J302.7, J303.1, J303.3, J304.1, J304.3, J304.4, J306.1, J308.1, J310.1, J312.1, Q300.3 (S), Q301.3 (S), R300.1, R302.1, R304.1, R306.1, U300.2, U301.2, U302.3 (GND), U302.8 (A1); also elsewhere on the board
INA_IN+: U302.1 (IN+); also elsewhere on the board
MSFT_1: J302.8, R300.2, R301.2
MSFT_2: J302.9, R304.2, R305.2
SCL: J302.6, U302.5 (SCL)
SDA: J302.5, U302.6 (SDA)

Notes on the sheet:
Servo 5V
MCU Connector
High power switches
VBAT Pass Through
Power Sensing
I2C address is 0x41
ESC Solder Pads

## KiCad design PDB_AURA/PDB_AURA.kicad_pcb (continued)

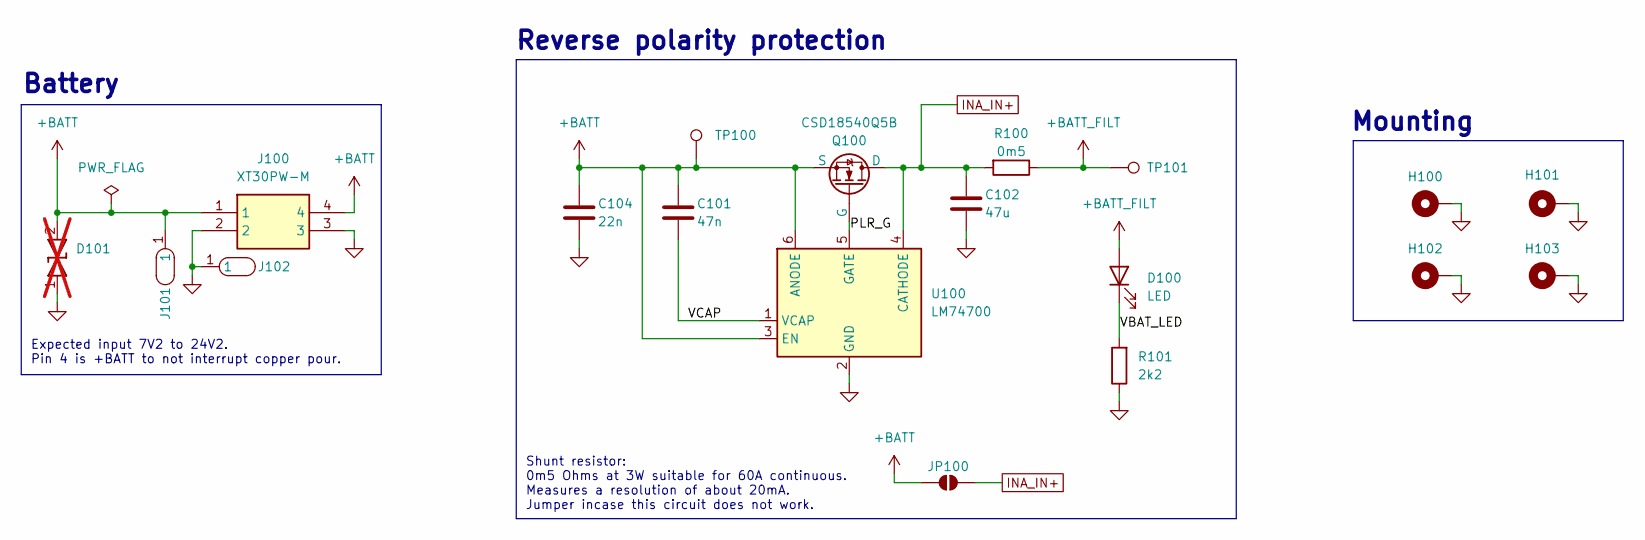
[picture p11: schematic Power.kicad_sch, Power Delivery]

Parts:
C101: 47n; C_0402_1005Metric
C102: 47u; C_1210_3225Metric
C104: 22n; C_0402_1005Metric
D100: LED; LED_0603_1608Metric
D101: SMBJ33CA; DIONM5436X244N; Manufacturer_Part_Number SMBJ33CA; Mouser Part Number 78-SMBJ33CA; not fitted
H100, H101, H102, H103: MountingHole_Pad; MountingHole_3.2mm_M3_Pad_Via
J100: XT30PW-M; XT30PWM; Manufacturer_Part_Number XT30PW-M
J101, J102: BAT_SOLDER_PAD
JP100: SolderJumper_2_Open; SolderJumper-2_P1.3mm_Open_RoundedPad1.0x1.5mm
Q100: CSD18540Q5B
R100: 0m5; R_2512_6332Metric
R101: 2k2; R_0402_1005Metric
TP100, TP101: TestPoint; TestPoint_Pad_D1.0mm
U100: LM74700; SOT-23-6

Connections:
+BATT: C101.1, C104.1, D101.2, J100.1, J100.4, J101.1, JP100.1 (A), Q100.3 (S), TP100.1, U100.3 (EN), U100.6 (ANODE)
+BATT_FILT: D100.2 (A), R100.1, TP101.1; also elsewhere on the board
/100_Power/PLR_G: Q100.1 (G), U100.5 (GATE)
/100_Power/VBAT_LED: D100.1 (K), R101.2
/100_Power/VCAP: C101.2, U100.1 (VCAP)
GND: C102.2, C104.2, D101.1, H100.1, H101.1, H102.1, H103.1, J100.2, J100.3, J102.1, R101.1, U100.2 (GND); also elsewhere on the board
INA_IN+: C102.1, JP100.2 (B), Q100.2 (D), R100.2, U100.4 (CATHODE); also elsewhere on the board

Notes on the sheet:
Mounting
Battery
Reverse polarity protection
Expected input 7V2 to 24V2. Pin 4 is +BATT to not interrupt copper pour.
Shunt resistor: 0m5 Ohms at 3W suitable for 60A continuous. Measures a resolution of about 20mA. Jumper incase this circuit does not work.

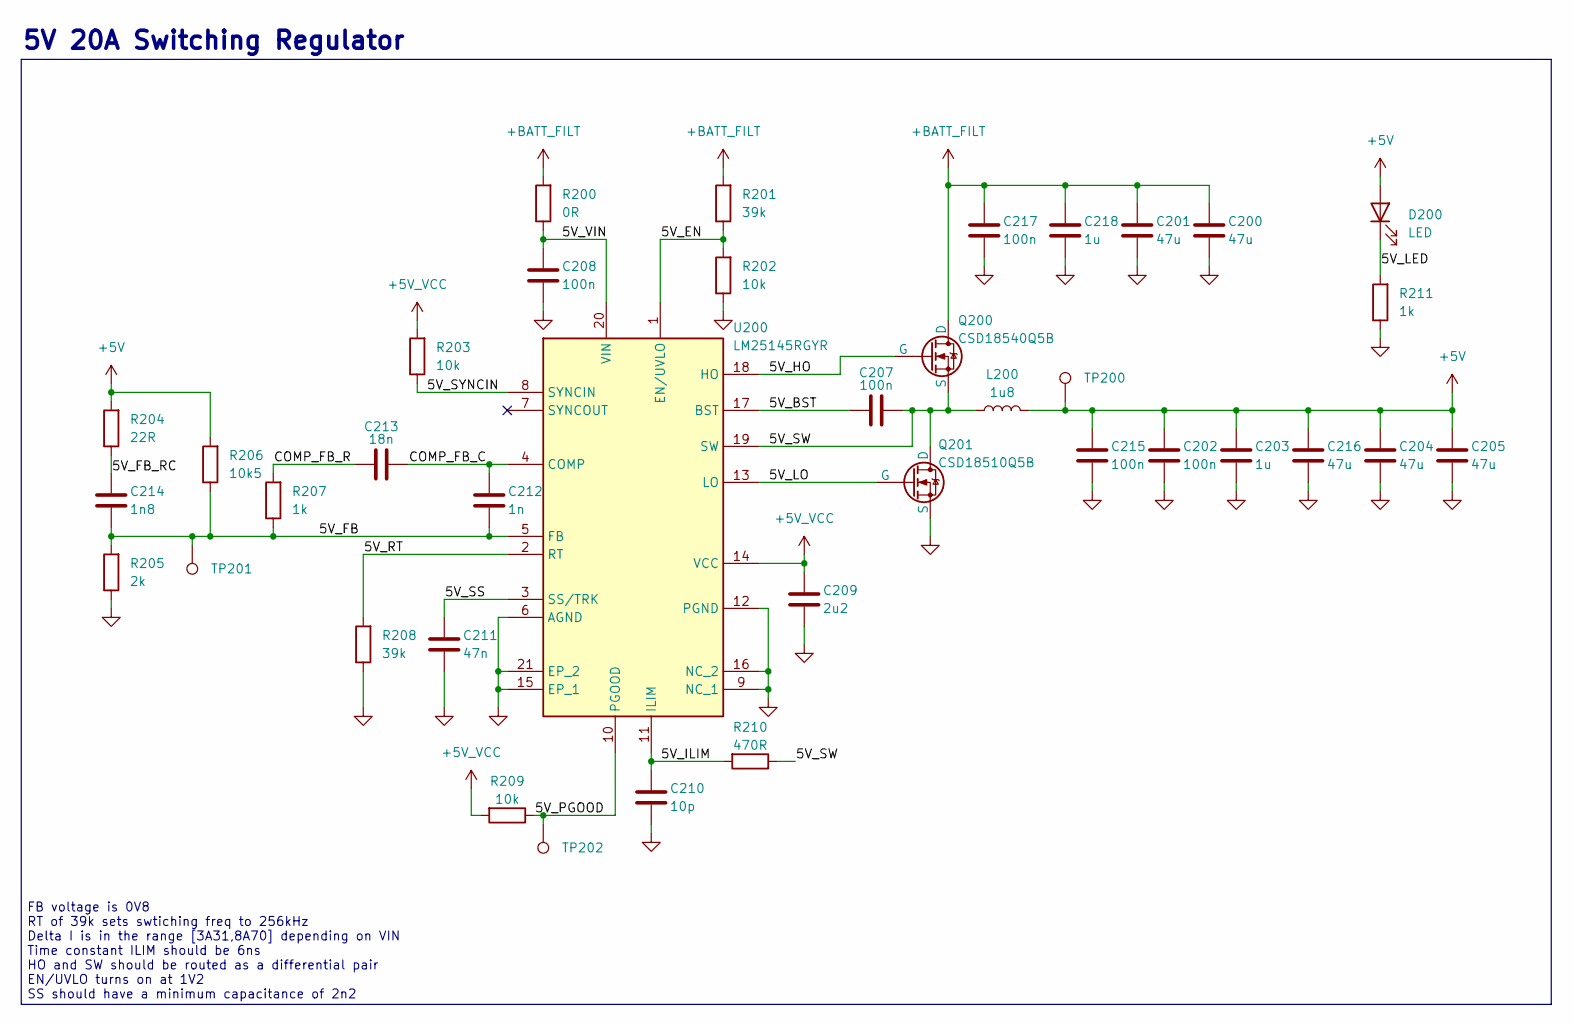
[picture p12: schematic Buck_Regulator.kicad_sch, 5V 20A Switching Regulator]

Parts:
C200, C201, C204, C205, C216: 47u; C_1210_3225Metric
C202, C207, C208, C215, C217: 100n; C_0402_1005Metric
C203, C218: 1u; C_0402_1005Metric
C209: 2u2; C_0402_1005Metric
C210: 10p; C_0402_1005Metric
C211: 47n; C_0402_1005Metric
C212: 1n; C_0402_1005Metric
C213: 18n; C_0402_1005Metric
C214: 1n8; C_0402_1005Metric
D200: LED; LED_0603_1608Metric
L200: 1u8; Untitled
Q200: CSD18540Q5B
Q201: CSD18510Q5B; CSD18540Q5BT
R200: 0R; R_0402_1005Metric; JLCPCB C25783
R201, R208: 39k; R_0402_1005Metric; JLCPCB C25783
R202, R203, R209: 10k; R_0402_1005Metric
R204: 22R; R_0402_1005Metric
R205: 2k; R_0402_1005Metric
R206: 10k5; R_0402_1005Metric
R207, R211: 1k; R_0402_1005Metric
R210: 470R; R_0402_1005Metric; JLCPCB C25091
TP200, TP201, TP202: TestPoint; TestPoint_Pad_D1.0mm
U200: LM25145RGYR; RGY0020B; Manufacturer_Part_Number LM25145RGYR; Mouser Part Number 595-LM25145RGYR

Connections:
+5V: C202.1, C203.1, C204.1, C205.1, C215.1, C216.1, D200.2 (A), L200.2, R204.2, R206.2, TP200.1; also elsewhere on the board
+5V_VCC: C209.1, R203.2, R209.2, U200.14 (VCC)
+BATT_FILT: C200.1, C201.1, C217.1, C218.1, Q200.2 (D), R200.2, R201.2; also elsewhere on the board
/200_Buck_Regulator/5V_BST: C207.1, U200.17 (BST)
/200_Buck_Regulator/5V_EN: R201.1, R202.2, U200.1 (EN/UVLO)
/200_Buck_Regulator/5V_FB: C212.2, C214.2, R205.2, R206.1, R207.1, TP201.1, U200.5 (FB)
/200_Buck_Regulator/5V_FB_RC: C214.1, R204.1
/200_Buck_Regulator/5V_HO: Q200.1 (G), U200.18 (HO)
/200_Buck_Regulator/5V_ILIM: C210.1, R210.2, U200.11 (ILIM)
/200_Buck_Regulator/5V_LED: D200.1 (K), R211.2
/200_Buck_Regulator/5V_LO: Q201.1 (G), U200.13 (LO)
/200_Buck_Regulator/5V_PGOOD: R209.1, TP202.1, U200.10 (PGOOD)
/200_Buck_Regulator/5V_RT: R208.2, U200.2 (RT)
/200_Buck_Regulator/5V_SS: C211.1, U200.3 (SS/TRK)
/200_Buck_Regulator/5V_SW: C207.2, L200.1, Q200.3 (S), Q201.2 (D), R210.1, U200.19 (SW)
/200_Buck_Regulator/5V_SYNCIN: R203.1, U200.8 (SYNCIN)
/200_Buck_Regulator/5V_VIN: C208.1, R200.1, U200.20 (VIN)
/200_Buck_Regulator/COMP_FB_C: C212.1, C213.2, U200.4 (COMP)
/200_Buck_Regulator/COMP_FB_R: C213.1, R207.2
GND: C200.2, C201.2, C202.2, C203.2, C204.2, C205.2, C208.2, C209.2, C210.2, C211.2, C215.2, C216.2, C217.2, C218.2, Q201.3 (S), R202.1, R205.1, R208.1, R211.1, U200.6 (AGND), U200.9 (NC_1), U200.12 (PGND), U200.15 (EP_1), U200.16 (NC_2), U200.21 (EP_2); also elsewhere on the board

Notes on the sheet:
FB voltage is 0V8 RT of 39k sets swtiching freq to 256kHz Delta I is in the range [3A31,8A70] depending on VIN Time constant ILIM should be 6ns HO and SW should be routed as a differential pair EN/UVLO turns on at 1V2 SS should have a minimum capacitance of 2n2
5V 20A Switching Regulator

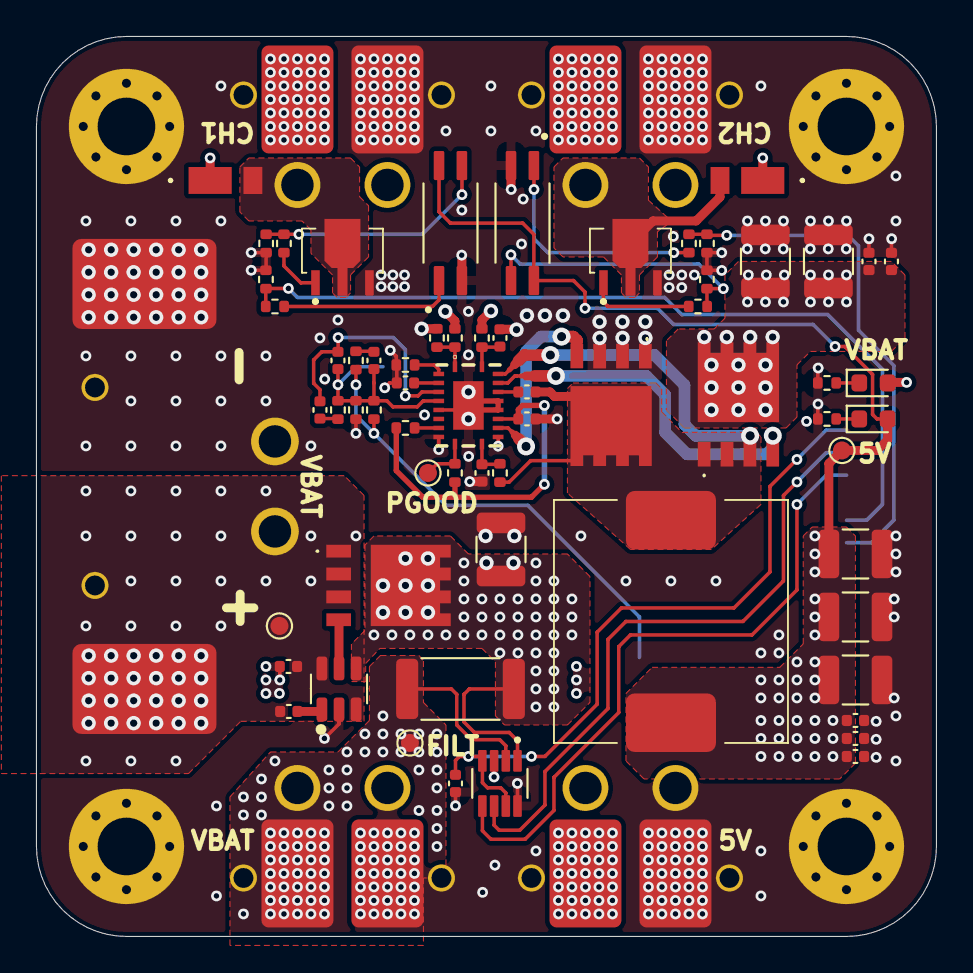
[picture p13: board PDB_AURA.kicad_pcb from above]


Board: 4 copper layers, 50.0 x 50.0 mm, 88 parts (14 on the bottom side), 38 nets.

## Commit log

2025-06-02 Started Editing
    Problem syncing desktop to laptop (libraries).
    [Connectors.kicad_sch, ESP32.kicad_sch, MCU_AURA.kicad_pcb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]
2025-06-03 Added Samacsys libraries
    Made the libraries from the component search engine local.
    [Connectors.kicad_sch, Digital_Peripherals.kicad_sch, ESP32.kicad_sch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]
2025-06-03 Adding 3D Models
    [Digital_Peripherals.kicad_sch, ESP32.kicad_sch, MCU_AURA.kicad_pcb]
2025-06-03 All CAD models synchronised
    [MCU_AURA.kicad_pcb]
2025-06-03 Adding Connectors
    [Connectors.kicad_sch, Digital_Peripherals.kicad_sch, ESP32.kicad_sch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]
2025-06-05 Initial Schematic Draft
    [Communication.kicad_sch, Connectors.kicad_sch, Digital_Peripherals.kicad_sch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]
2025-06-06 Initial draft
    [MCU_AURA.kicad_pcb, PDB_AURA.kicad_pcb, PDB_AURA.step]
2025-06-10 Started Routing
    [Connectors.kicad_sch, Digital_Peripherals.kicad_sch, ESP32.kicad_sch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]
2025-06-11 First fully routed version
    [Digital_Peripherals.kicad_sch, ESP32.kicad_sch, MCU_AURA.kicad_pcb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]
2025-06-12 First version
    [MCU_AURA.kicad_pcb, Power.kicad_sch]
2025-06-16 New PDB specs chosen
    [Connectors.kicad_sch, PDB_AURA.kicad_pcb, Power.kicad_sch]
2025-06-19 Moving to laptop
    [Buck_Regulator.kicad_sch, Connectors.kicad_sch, PDB_AURA.kicad_pcb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]
2025-06-20 Annotated schematic for PDB
    [Buck_Regulator.kicad_sch, Connectors.kicad_sch, PDB_AURA.kicad_pcb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]
2025-06-20 Second Layout Attempt
    Renamed all components and placed them all.
    [Buck_Regulator.kicad_sch, Connectors.kicad_sch, PDB_AURA.kicad_pcb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]
2025-06-21 Started Routing 2
    Forgot to save the pcb.
    [PDB_AURA.kicad_pcb]
2025-06-21 Continued Routing
    [Connectors.kicad_sch, PDB_AURA.kicad_pcb]
2025-06-22 First PDB Version
    [Buck_Regulator.kicad_sch, PDB_AURA.kicad_pcb]
2025-06-25 Second Iteration
    [Buck_Regulator.kicad_sch, MCU_AURA.kicad_pcb, PDB_AURA.kicad_pcb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]
2025-06-28 Replaced JTAG with Flash
    JTAG is used through USB so a Flash chip was added to MCU. PDB is just being cleaned up currently.
    [Connectors.kicad_sch, Digital_Peripherals.kicad_sch, ESP32.kicad_sch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]
2025-06-28 Fixed LM2514 Layout
    Followed datasheet guidelines for the SW and HO traces.
    [PDB_AURA.kicad_pcb]
2025-06-29 New Component Values
    [Buck_Regulator.kicad_sch, Connectors.kicad_sch, PDB_AURA.kicad_pcb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]
2025-07-01 Re Routing some of the power board
    Connectors had positive and negative the wrong way around, and some of the routing did not look good.
    [Connectors.kicad_sch, PDB_AURA.kicad_pcb]
2025-07-05 First review for PDB.
    [PDB_AURA-B_Cu.gbr, PDB_AURA-B_Mask.gbr, PDB_AURA-B_Paste.gbr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]
2025-07-07 Second Iteration MCU
    [Connectors.kicad_sch, Digital_Peripherals.kicad_sch, ESP32.kicad_sch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]
2025-07-08 Second iteration PDB
    [Buck_Regulator.kicad_sch, PDB_AURA.kicad_pcb, Power.kicad_sch]
2025-07-10 PDB organised
    [Buck_Regulator.kicad_sch, LM25145_quickstart_calculator_A5.xlsm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]
2025-07-10 Production Files
    [MCU_AURA.csv, PDB_AURA.csv, PDB_AURA_V2.csv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]
2025-07-11 Production Files for MCU
    [Connectors.kicad_sch, Digital_Peripherals.kicad_sch, ESP32.kicad_sch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]
2025-07-11 CPL file finalised for MCU
    [MCU_AURA-B_Cu.gbr, MCU_AURA-B_Mask.gbr, MCU_AURA-B_Silkscreen.gbr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]
2025-07-12 Silk Screen Done
    [Connectors.kicad_sch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]
2025-07-13 First Order
    [Connectors.kicad_sch, ESP32.kicad_sch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]
2025-07-24 SD Card Models
    [MCU_AURA.kicad_pcb]
2025-09-01 Deleted old files
    [Communication.kicad_sch, Digital_Peripherals.kicad_sch, ESP32.kicad_sch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]
2025-09-01 Create solder pad footprints
2025-09-01 Synchronised project outline and block diagram
    [PDB_AURA.kicad_sch]
2025-09-01 Tidied up PDB schematic for documentation.
    [Connectors.kicad_sch, Power.kicad_sch]
2025-09-01 Added exported schematic PDFs
